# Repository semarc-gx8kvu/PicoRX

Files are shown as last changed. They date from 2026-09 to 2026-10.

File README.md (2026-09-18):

SEMARC Version of the PicoRX
============================

As a group we have taken Jon Dawson's design and created:

+ Our own PCB
+ The Box
+ Modifications to the Code

How we modify this fork is up to us as a group. I'm going to suggest that we have a *SEMARC* folder that contains our PCB and Box designs. But we *shouldn't* put code changes in there. I suggest that we put code changes in branches, and then decide as a group whether to include these in the main branch, or maybe even consider submitting pull requests to Jon's original repository.

Pi Pico Rx - A crystal radio for the digital age?
=================================

My first step into the world of electronics was with a crystal radio, just like this one. 

crystal radio

Back then, I don't think it has ever occurred to me that I could make a radio myself, so I wasn't expecting it to work. But when I put the earphone in, I was amazed to hear very faint sounds coming through. I couldn't believe that building a radio could be so simple, and the best part was, it didn't need any batteries! That little experience sparked my interest in electronics.

Times have certainly changed since then, and today, we find ourselves in a golden age for electronics enthusiasts. Back in the ninteen eightees, I could have never imagined that my pocket money would one day buy a device with computing power that could have filled an entire room just a few decades ago.

I often wonder how we can still capture that sense of awe and excitement from my first crystal radio experience. Is it still possible to create something simple yet captivating? 

The Pi Pico Rx - may be the answer to that question. While it may not be quite as straightforward as the crystal radio, the Pi Pico Rx presents a remarkably simple solution. Armed with just a [Raspberry Pi Pico](https://www.raspberrypi.com/products/raspberry-pi-pico/), an analogue switch, and an op-amp, we now have the power to construct a capable SDR receiver covering the LW, MW, and SW bands. With the ability to receive signals from halfway around the globe. I can't help but think that my younger self would have been truly impressed!

concept

Features
--------

+ 0 - 30MHz coverage
+ 250kHz bandwidth SDR reciever
+ CW/SSB/AM/FM reception
+ OLED display
+ simple spectrum scope
+ Headphones/Speaker
+ 500 general purpose memories
+ runs on 3 AAA batteries
+ less than 50mA current consumption

Development
-----------

concept

Pi Pico Rx is currently at the experimental prototyping stage, but it does work. [Read the Docs](https://101-things.readthedocs.io/en/latest/radio_receiver.html) for more technical details!

Getting the Code
----------------

You can find a precompiled binary for PiPicoRx [here](https://github.com/dawsonjon/PicoRX/releases). If you want to build from the C++ source files, follow these instructions.

```
  sudo apt install git
  git clone https://github.com/dawsonjon/PicoRX.git
  cd PicoRX
  git submodule init
  git submodule update
```

User Manual
-----------

You can find the user manual for the PiPicoRx [here](https://github.com/dawsonjon/PicoRX/raw/master/user_manual/Pi%20Pico%20Rx%20User%20Manual.pdf).

Install Pi Pico SDK
-------------------

Follow the [Getting started with the Raspberry Pi Pico](https://datasheets.raspberrypi.com/pico/getting-started-with-pico.pdf) quick start guide to install the C/C++ SDK.

```
  sudo apt install wget #if wget not installed
  wget https://raw.githubusercontent.com/raspberrypi/pico-setup/master/pico_setup.sh
  chmod +x pico_setup.sh
  ./pico_setup.sh
```

For windows users, this page provides and [installer](https://www.raspberrypi.com/news/raspberry-pi-pico-windows-installer/) that makes the process much simpler.

Build Projects
--------------

```
  mkdir build
  cd build
  cmake -DPICO_BOARD=pico -DPICO_SDK_PATH=~/pico/pico-sdk ..
  make
```

```
  mkdir build
  cd build
  cmake -DPICO_SDK_PATH=~/pico/pico-sdk -DPICO_BOARD=pico2 -DPICO_PLATFORM=rp2350-arm-s ..
  make
```

```
  mkdir build
  cd build
  cmake -DPICO_SDK_PATH=~/pico/pico-sdk -DPICO_BOARD=pico2 -DPICO_PLATFORM=rp2350-riscv ..
  make
```

Credits
-------

Massive thanks to everybody who has contributed and given feedback on this project. Thanks to
all your efforts, we’re closer than ever to making radio more accessible,
innovative, and community-driven.

The project uses the Universal 8-bit Graphics Library (u8g2) library by
olikraus@gmail.com, the pico_ssd1306 display library by David Schramm and the
ILI934X display driver by Darren Horrocks.

Special Thanks to:

Mariusz Ryndzionek for contributing IQ Imbalance Correction, De-emphasis
filter, USB audio, U8G2 integration, Synronous AM Demodulation and many other
enhancements.

Penfold42 for Gain Calibration, Frequency Scanning, Spectrum Zoom, Multiple home screen
views, Animated Splash Screen, Support for multiple displays/configurations and
many other enhancements.

Robert Nickels (W9RAN) and Jim Reagan (W0CHL) for their support and
encouragements and for the enormous effort they have both put in testing,
debugging, feedback and suggestions.

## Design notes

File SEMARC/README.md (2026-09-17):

SEMARC Specific Folder
======================

This folder should contain things that are only relevant to our group. That will include the case and the PCB.

I suggest that have sub-folders, maybe **case** or **box** and **PCB**. But I'll leave that to whoever adds the files. For now, the files should added straight onto the master branch.

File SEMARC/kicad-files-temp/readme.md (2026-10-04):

# How I added these files

From my laptop, I opened a powershell terminal and typed in the following commands:

```powershell
git clone git@github.com:semarc-gx8kvu/PicoRX.git
cd .\PicoRX\
git branch m0twm-add-kicad-files
git checkout m0twm-add-kicad-files
```

I then added the files in file explorer

Back in powershell, I executed the following commands:

```powershell
git add *
git commit -m 'Add schematics and pcb layouts'
git push --set-upstream origin m0twm-add-kicad-files
```

On the github website, the new branch automatically shows up and prompts you to submit a **pull request**:

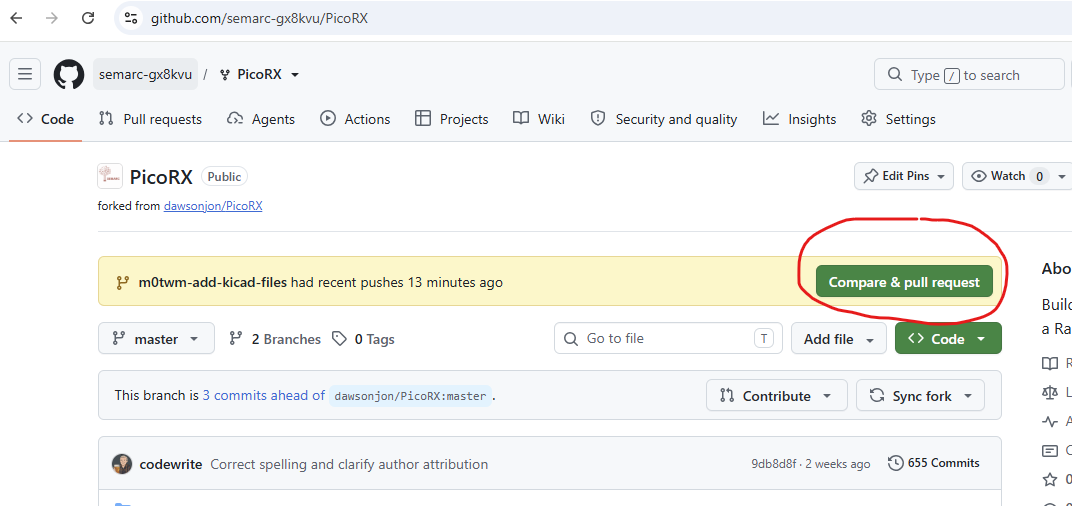
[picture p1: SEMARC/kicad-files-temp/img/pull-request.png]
Pull Request


On the next page, you get to name the pull request and set a description. Because this is a forked repository, you have to set the repository to the SEMARC one, because by default it will send a pull request to the base repository (jondawson) and you probbaly don't want that!

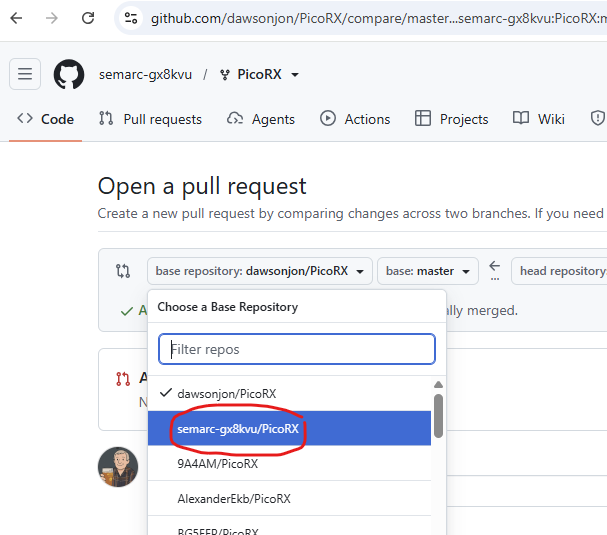
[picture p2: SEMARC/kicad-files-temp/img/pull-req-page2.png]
Pull Request Page 2


Admins get notified, and should approve the pull request as soon as possible. This is the standard approach and ensures that there are no conflicts. The files are now available on the main branch (which in this case is called master).

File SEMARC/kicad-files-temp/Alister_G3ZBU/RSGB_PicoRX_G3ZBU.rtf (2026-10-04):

RSGB Construction Competition 2026
Entry by Al Watt, G3ZBU

The PicoRX.

A few years ago I submitted an entry which used a Raspberry Pi Pico’s PIO subsystem as a 0-30MHz quadrature signal generator. That idea has been taken to a considerably higher level by Jon Dawson and his design published online in GitHub and 101 Things. I am sure that he did not copy my signal generator design because it seems to be an obvious thing to do with it.

The SEMARC club has chosen this project for 2026 and will design PCBs and housings.

His PicoRX is a fully-featured minimal-cost long-wave to 30MHz receiver and decodes AM, FM, LSB, USB and CW. All it requires is a £5 Pico, cheap OLED display, 3 push-buttons, shaft encoder, cheap dual op-amp and a multiplexer IC, plus a few resistors and capacitors. The receiver can be improved by the addition of band-pass filters and an Si5351 module if one really wants to splash out. His design uses surface-mount low-pass filters but my build will use larger components with legs, for experimentation.

The Pico has two 12-bit ADCs and they collect I and Q samples from a low IF of DC to 12kHz. Oversampling is enabled and that gives an improvement on the dynamic range. A pre-amp would be useful for the higher bands but on 40m the performance is perfectly acceptable thought broadcast interference could be an issue at night. There is excellent AGC, all done in software.

Another brilliant feature is the USB interface which provides audio output and CAT commands. This is similar to rigs costing £1,000. FLDIGI can be used to decode RTTY, PSK and MFSK signals. I have also used it with EI5DI’s SD logger. It also runs under DXLab Commander, so a PC can be used to select mode and frequency. CAT control is sent to COM3 on this Windows PC.

Because the minimum build would cost about £10 + PCB, it is ideal for schools. There are 512 memories covering not only Amateur bands but also LW, MW and SW broadcast stations, plus all the 27MHz CB channels. These may be easily changed and downloaded into the Pico.

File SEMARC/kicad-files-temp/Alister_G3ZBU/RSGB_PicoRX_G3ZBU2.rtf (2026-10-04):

RSGB Construction Competition 2026
Entry by Al Watt, G3ZBU, 27th Feb 2026.

The PicoRX.

A few years ago I submitted an entry which used a Raspberry Pi Pico’s PIO subsystem as a 0-30MHz quadrature signal generator. That idea has been taken to a considerably higher level by Jon Dawson and his design as published online in GitHub and 101 Things. I am sure that he did not copy my signal generator design because it seems to be an obvious thing to do with it.

The SEMARC club has chosen this project for 2026 and will design PCBs and housings.

His PicoRX is a fully-featured minimal-cost long-wave to 30MHz receiver and decodes AM, FM, LSB, USB and CW. All it requires is a £5 Pico, cheap OLED display, 3 push-buttons, shaft encoder, cheap dual op-amp and a multiplexer IC, plus a few resistors and capacitors. The receiver can be improved by the addition of band-pass filters, a small TFT screen and an Si5351 module if one really wants to splash out. His design uses surface-mount low-pass filters but my build will use larger components with legs, for experimentation.

The Pico has two 12-bit ADCs and they collect I and Q samples from a low IF of DC to 12kHz, from a Tayloe mixer. Oversampling is enabled and that gives an improvement on the dynamic range. A pre-amp would be useful for the higher bands but on 40m the performance is perfectly acceptable though Jon states that broadcast interference could be an issue at night. I have yet to try filters but they would be useful in attenuating any reception at multiples of the operating frequency.

There is excellent AGC, it’s all done in software as opposed to PIN diodes etc.

Another brilliant feature is the USB interface (USB as in Universal Serial Bus) which provides both audio output and CAT commands. This is similar to rigs costing upwards of £1,000. FLDIGI can be used to decode RTTY, PSK and MFSK signals. I have also used the USB CAT with EI5DI’s SD logger so that typing a frequency into the call-sign box causes the PicoRX to jump to that frequency. CAT also runs under DXLab Commander, so a PC can be used to select mode and frequency. CAT control is sent via COM3 on this Windows PC. However I have not yet managed to get FLRIG to play.

Another problem is that there are audible clicks when the tuning knob is rotated and Jon suggests that it is because the CPU clock is being reset to another frequency. That is done because the PIO subsystem cannot generate enough frequency resolution on the higher bands.

There are many Amateurs who are not keen on rigs with loads of menus and far prefer buttons, switches and knobs to perform the desired function. I have modified the software such that it uses two unallocated UART pins on the Pico to enable CAT by serial data. For a proof-of-concept I have connected this new serial data pair to a PIC which reads three push-buttons and controls green and red LEDs in each of the three switches. I have labelled these switches USB, CW and LSB. When a switch is pressed, its green LED is switched on and the relevant CAT command sent to the Pico at 19,200Bd. Poll commands are sent every second and the return packet is used to clear the green LED and switch on the correct red LED. In principal, I can extend the push-button scheme by adding more PICs, and I could also add potentiometers easily and build a menu-free receiver.

Because the minimum build would cost about £10 + PCB, it is ideal for schools. There are 512 memories covering not only most Amateur bands but also LW, MW and SW broadcast stations, plus all the 27MHz CB channels. These may be easily changed and downloaded into the Pico using a CSV formatted file.

I intend to generate an Amateur-only CSV file which includes all our band allocations. These can include the most popular FreeDV channels as that is a very exciting ‘new’ mode (I think it’s over 10 years old actually!); FreeDV can be decoded by a free program running on a PC or laptop and connected with the USB CAT/audio cable.

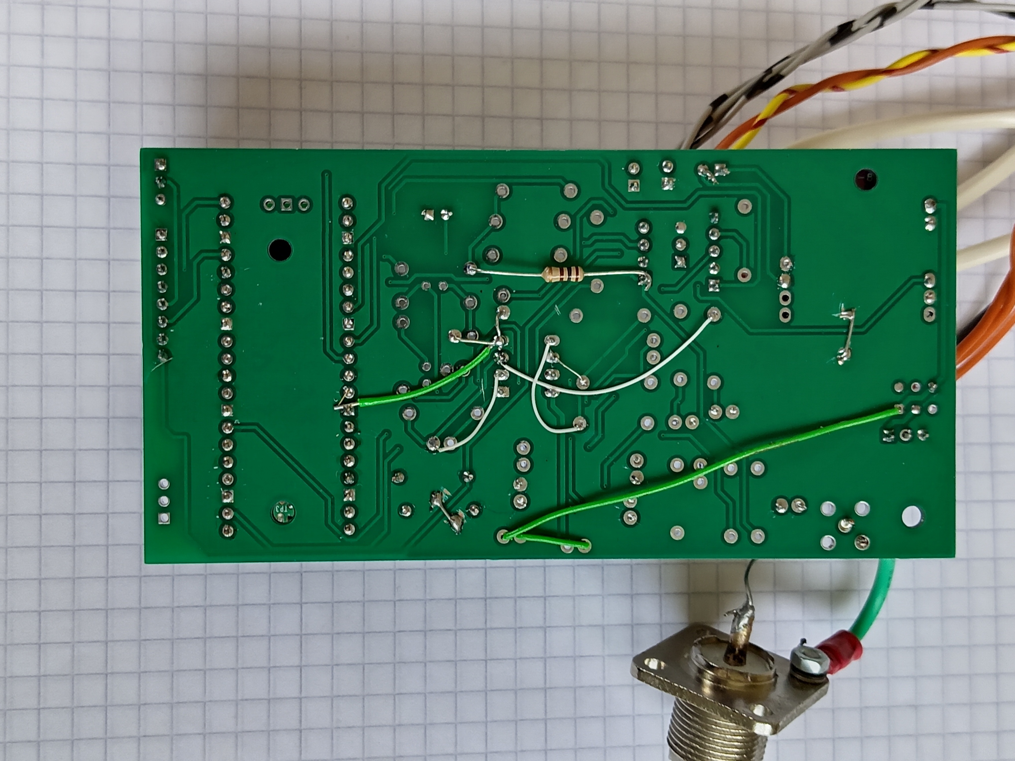
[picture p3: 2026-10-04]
SEMARC/kicad-files-temp/Alister_G3ZBU/IMG_20260323_111353_bot.jpg

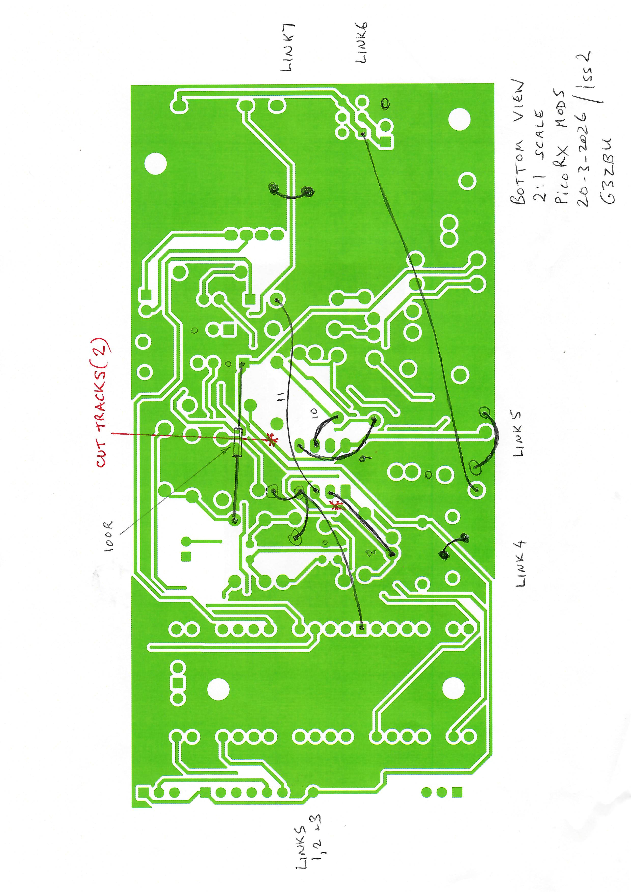
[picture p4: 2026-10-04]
SEMARC/kicad-files-temp/Alister_G3ZBU/scanPicoRX_bot_iss2.jpg

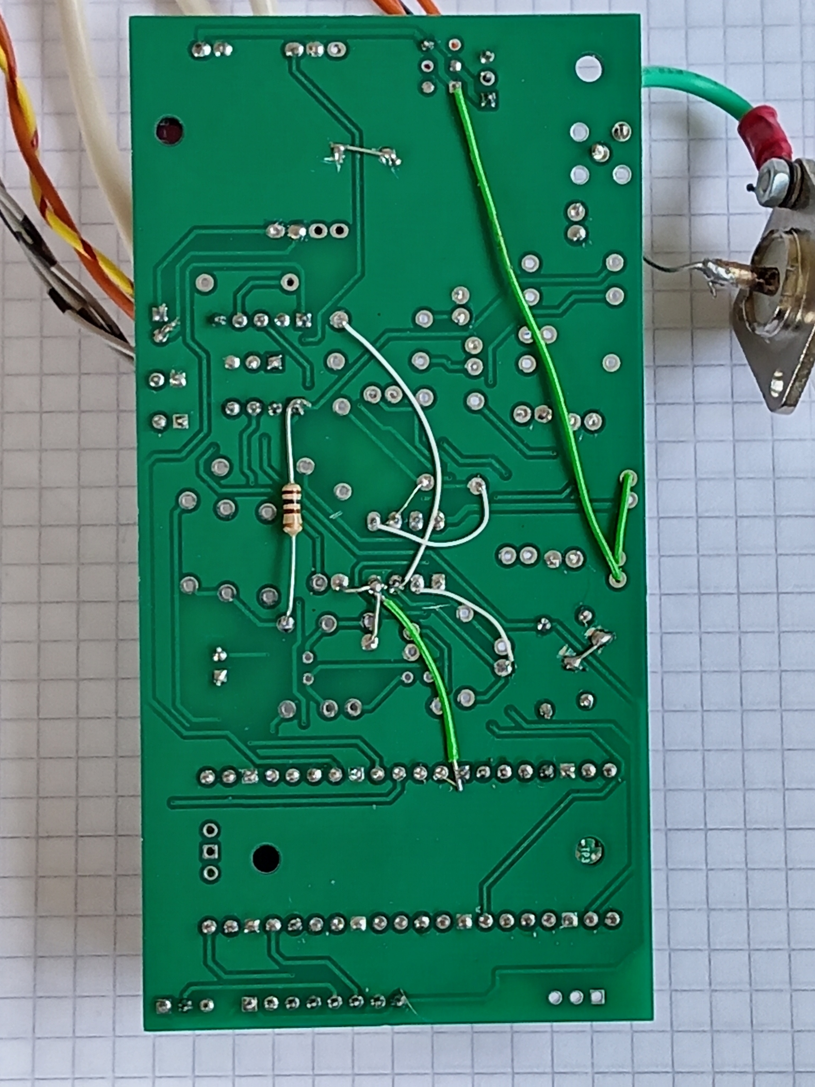
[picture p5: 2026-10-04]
SEMARC/kicad-files-temp/Alister_G3ZBU/IMG_20260323_111336_bot.jpg

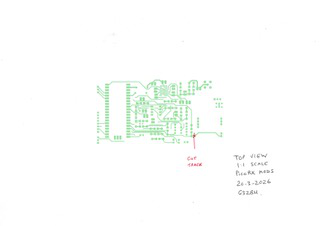
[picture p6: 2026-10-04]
SEMARC/kicad-files-temp/Alister_G3ZBU/scanPicoRX_TOP.jpeg

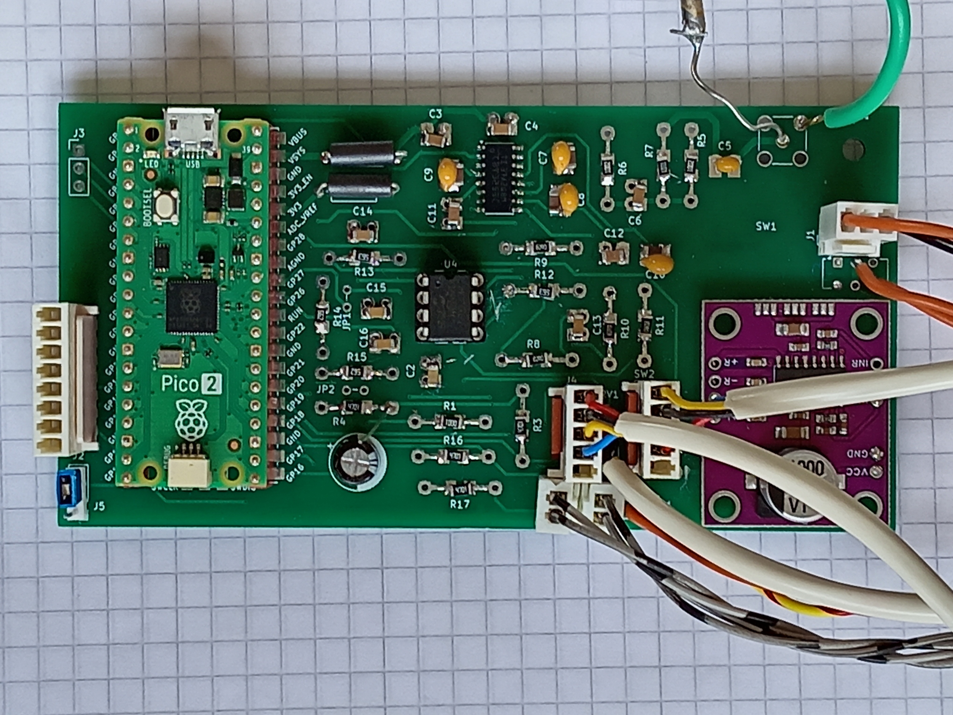
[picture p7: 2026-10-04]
SEMARC/kicad-files-temp/Alister_G3ZBU/IMG_20260323_111321_top.jpg

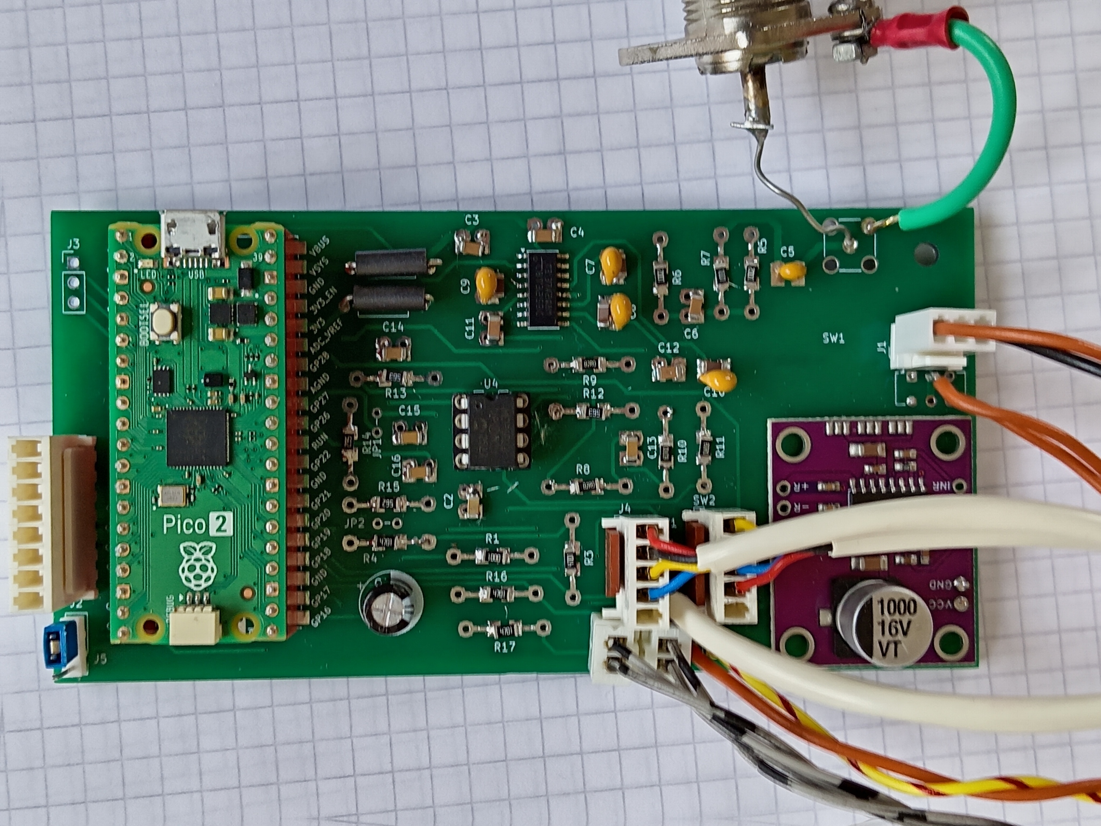
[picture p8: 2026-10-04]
SEMARC/kicad-files-temp/Alister_G3ZBU/IMG_20260323_111430_top.jpg

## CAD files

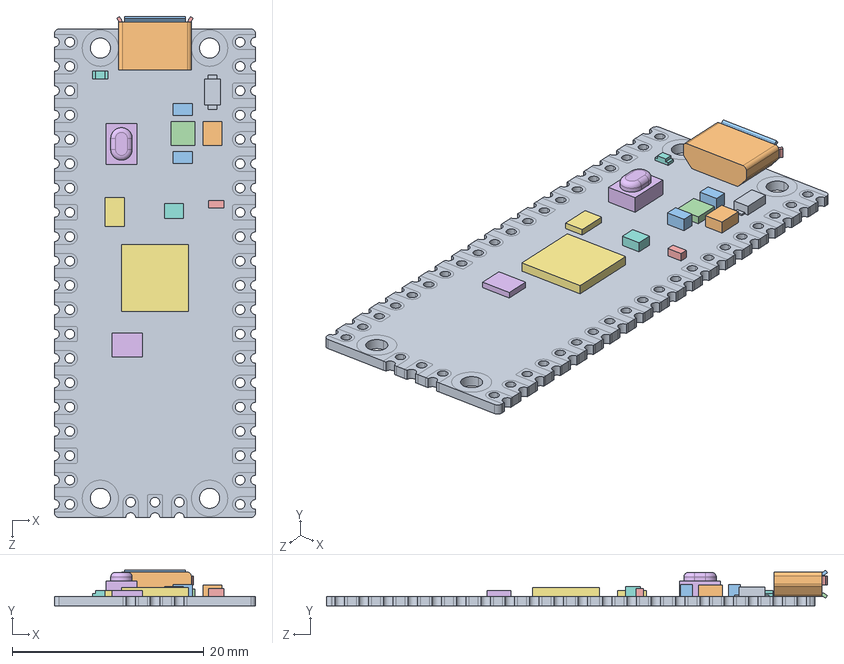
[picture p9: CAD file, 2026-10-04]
SEMARC/kicad-files-temp/Rob_G8ZAX/pico2.step
21.0 x 3.73 x 52.3 mm
PICO_REF_BOARD
PICO_REF_USB
PICO_REF_SWITCH
PICO_REF_MICROCONTROLLER
PICO_REF_LED
PICO_REF_COMP_1
PICO_REF_COMP_2
PICO_REF_COMP_3 x 2
PICO_REF_COMP_4
PICO_REF_COMP_5
PICO_REF_COMP_6
PICO_REF_COMP_7
PICO_REF_INDUCTOR

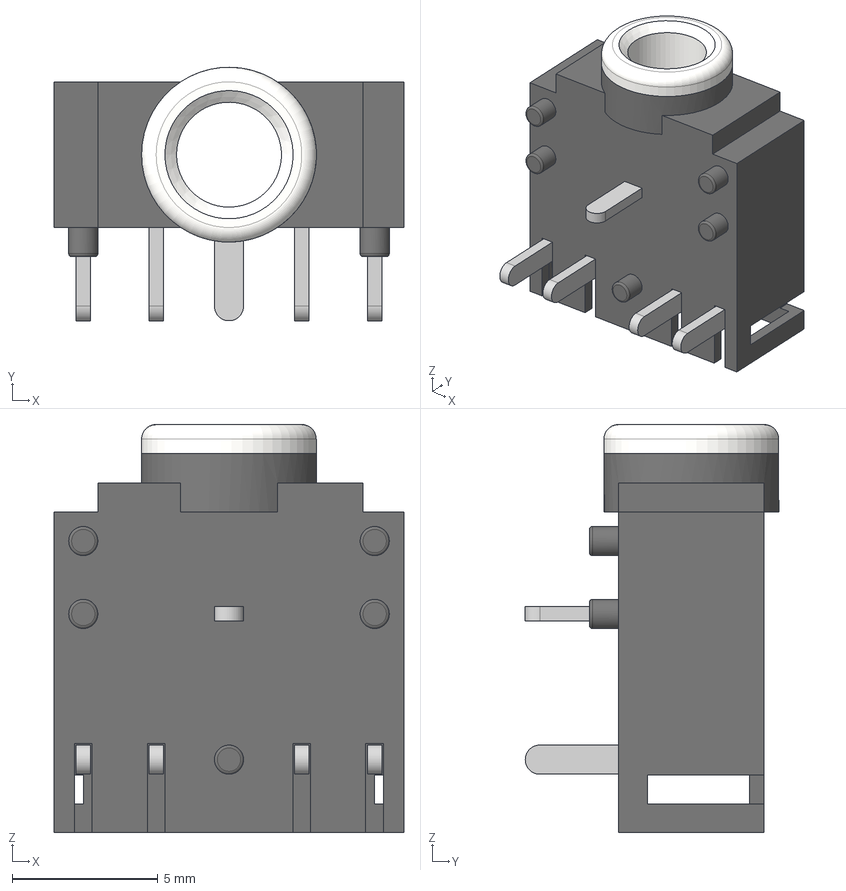
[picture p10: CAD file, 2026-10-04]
SEMARC/kicad-files-temp/Rob_G8ZAX/PicoRX_Footprints/pj-307.step
12.0 x 8.70 x 14.0 mm

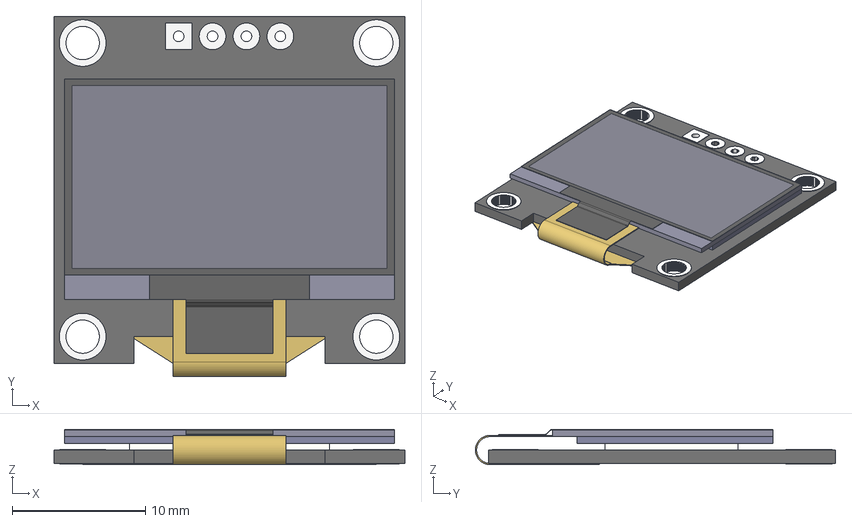
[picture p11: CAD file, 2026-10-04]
SEMARC/kicad-files-temp/Rob_G8ZAX/Display_OLED_0.96_128x64.step
26.3 x 27.0 x 2.65 mm
Body - PCB
Body - Back Panel
Body - Adhesive Pad
Body - Front Panel
Body - Flex Connector Bend
Body - Flex Connector Terminals
Body - Black Tape
Body - Protective Foil
Body - Screen Border
Extrude - Annular Rings

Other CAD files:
SEMARC/kicad-files-temp/Rob_G8ZAX/Pico-R3.step

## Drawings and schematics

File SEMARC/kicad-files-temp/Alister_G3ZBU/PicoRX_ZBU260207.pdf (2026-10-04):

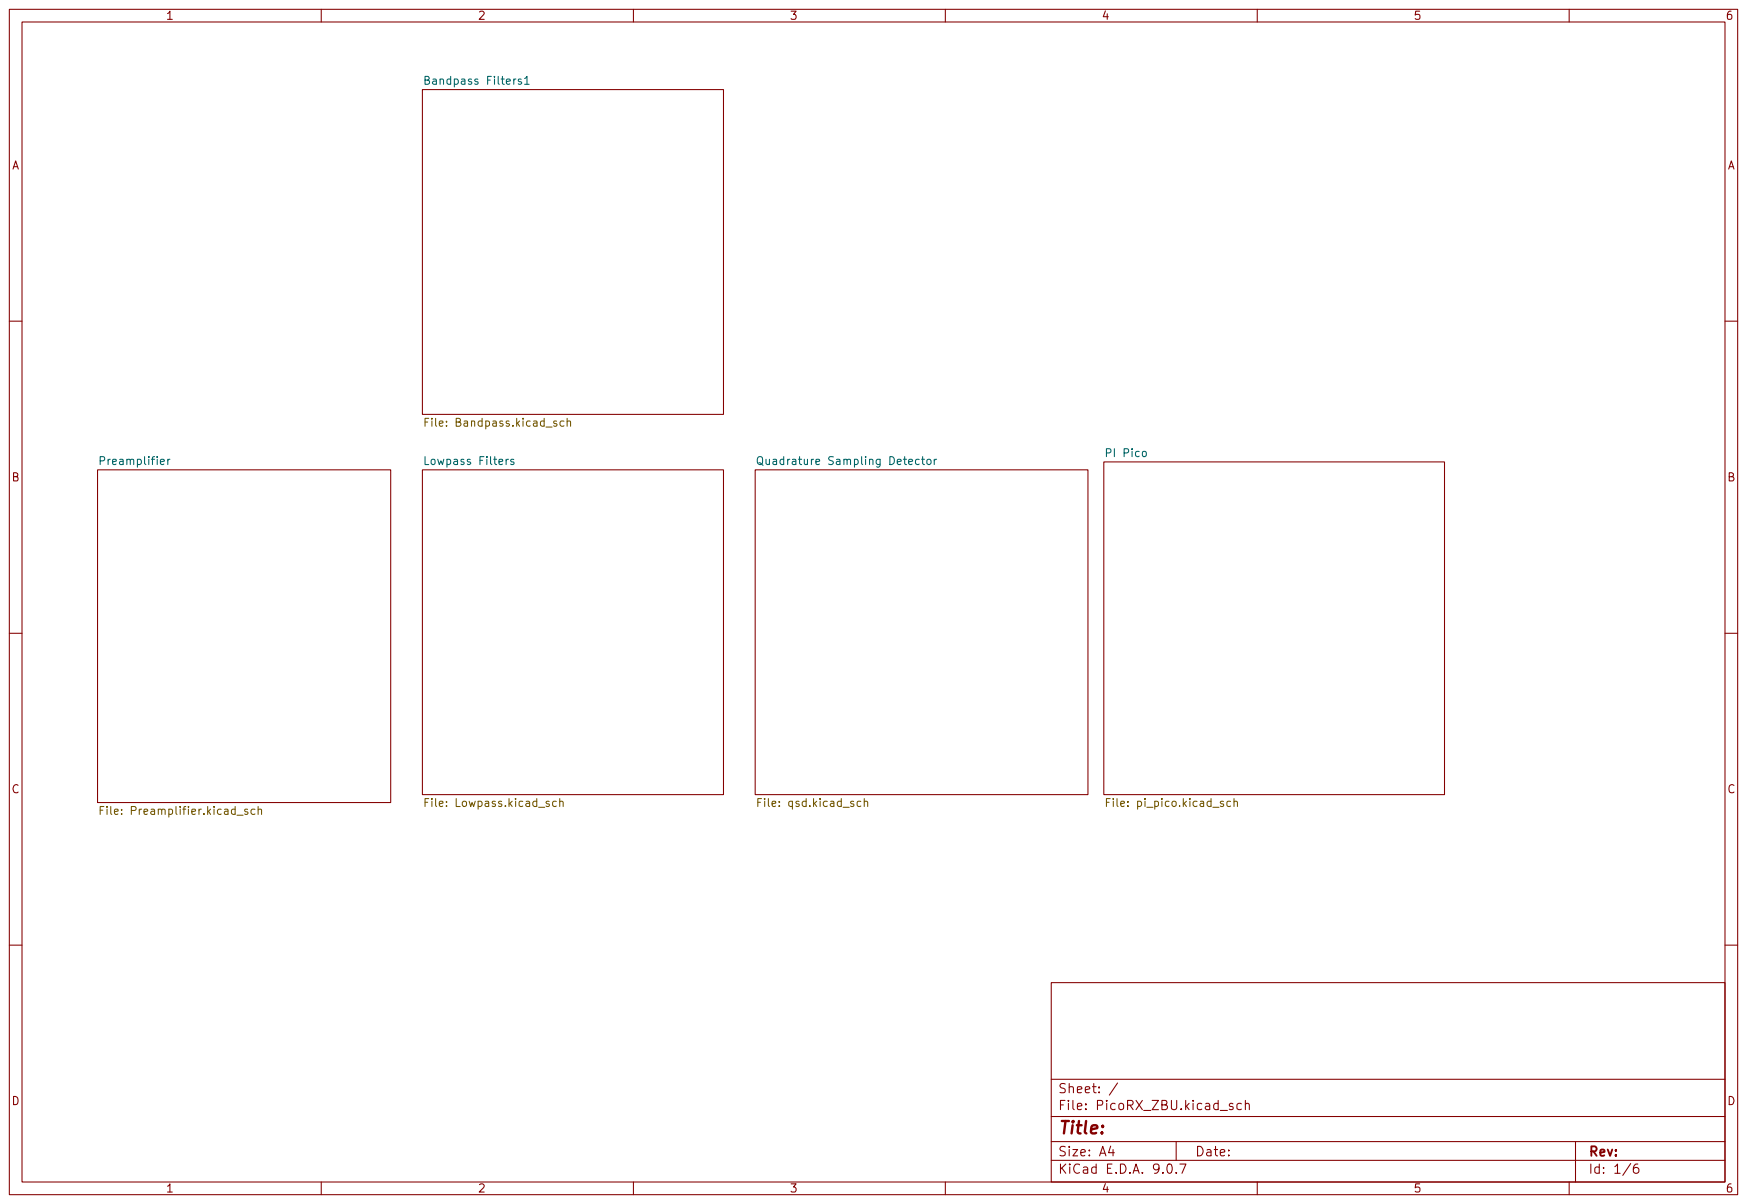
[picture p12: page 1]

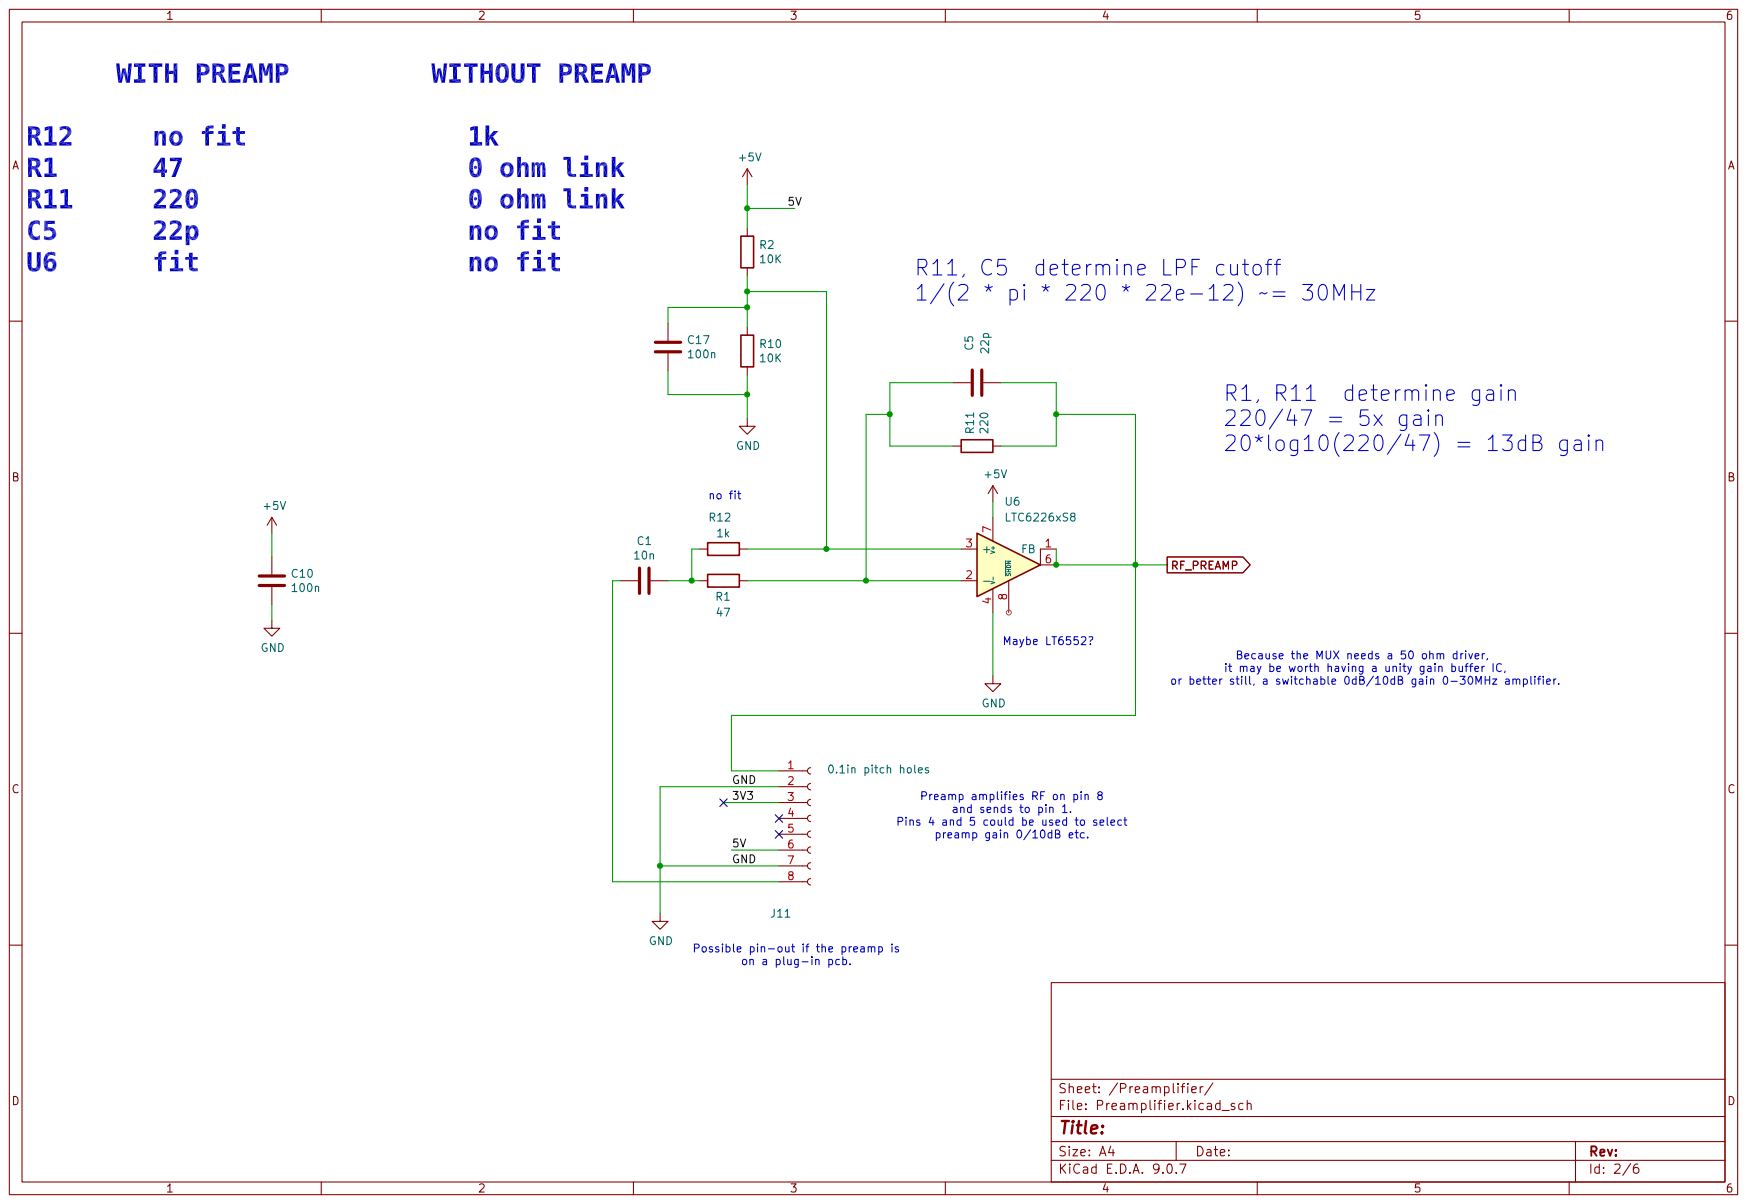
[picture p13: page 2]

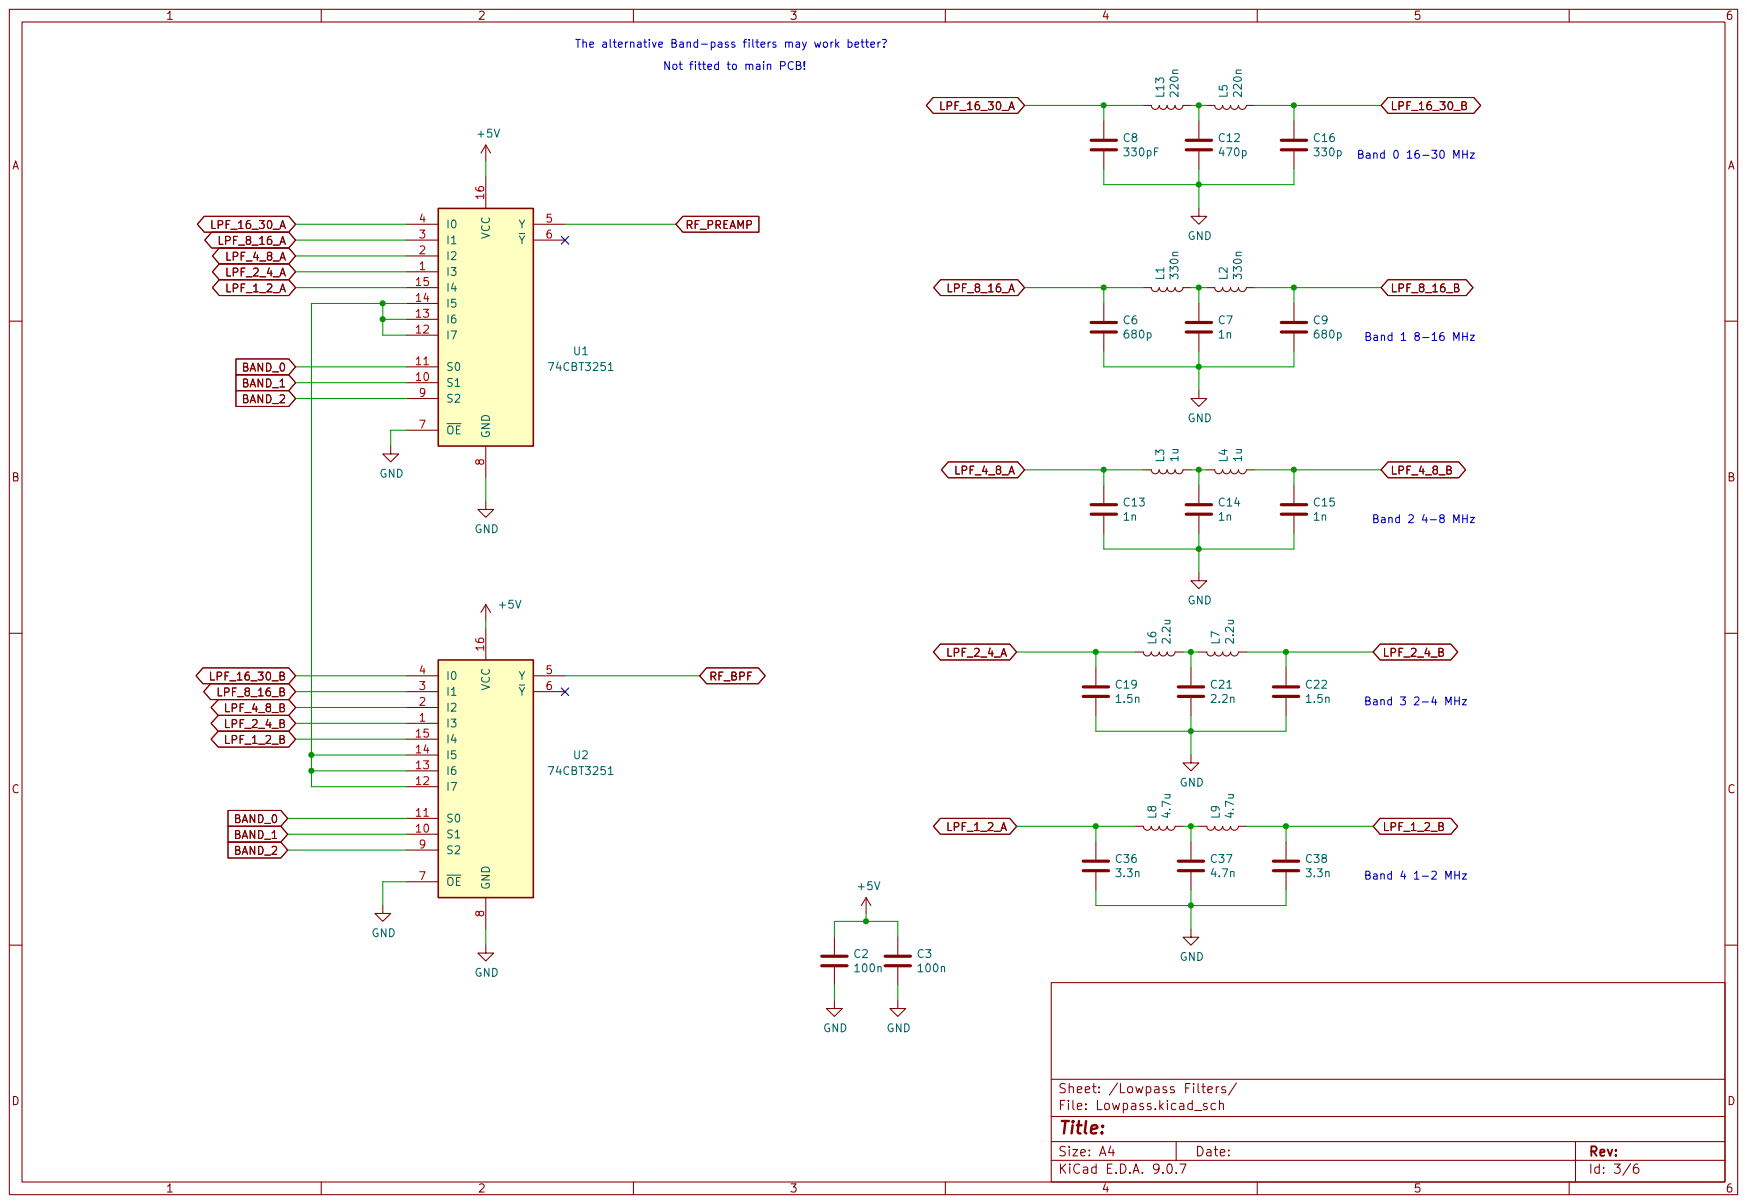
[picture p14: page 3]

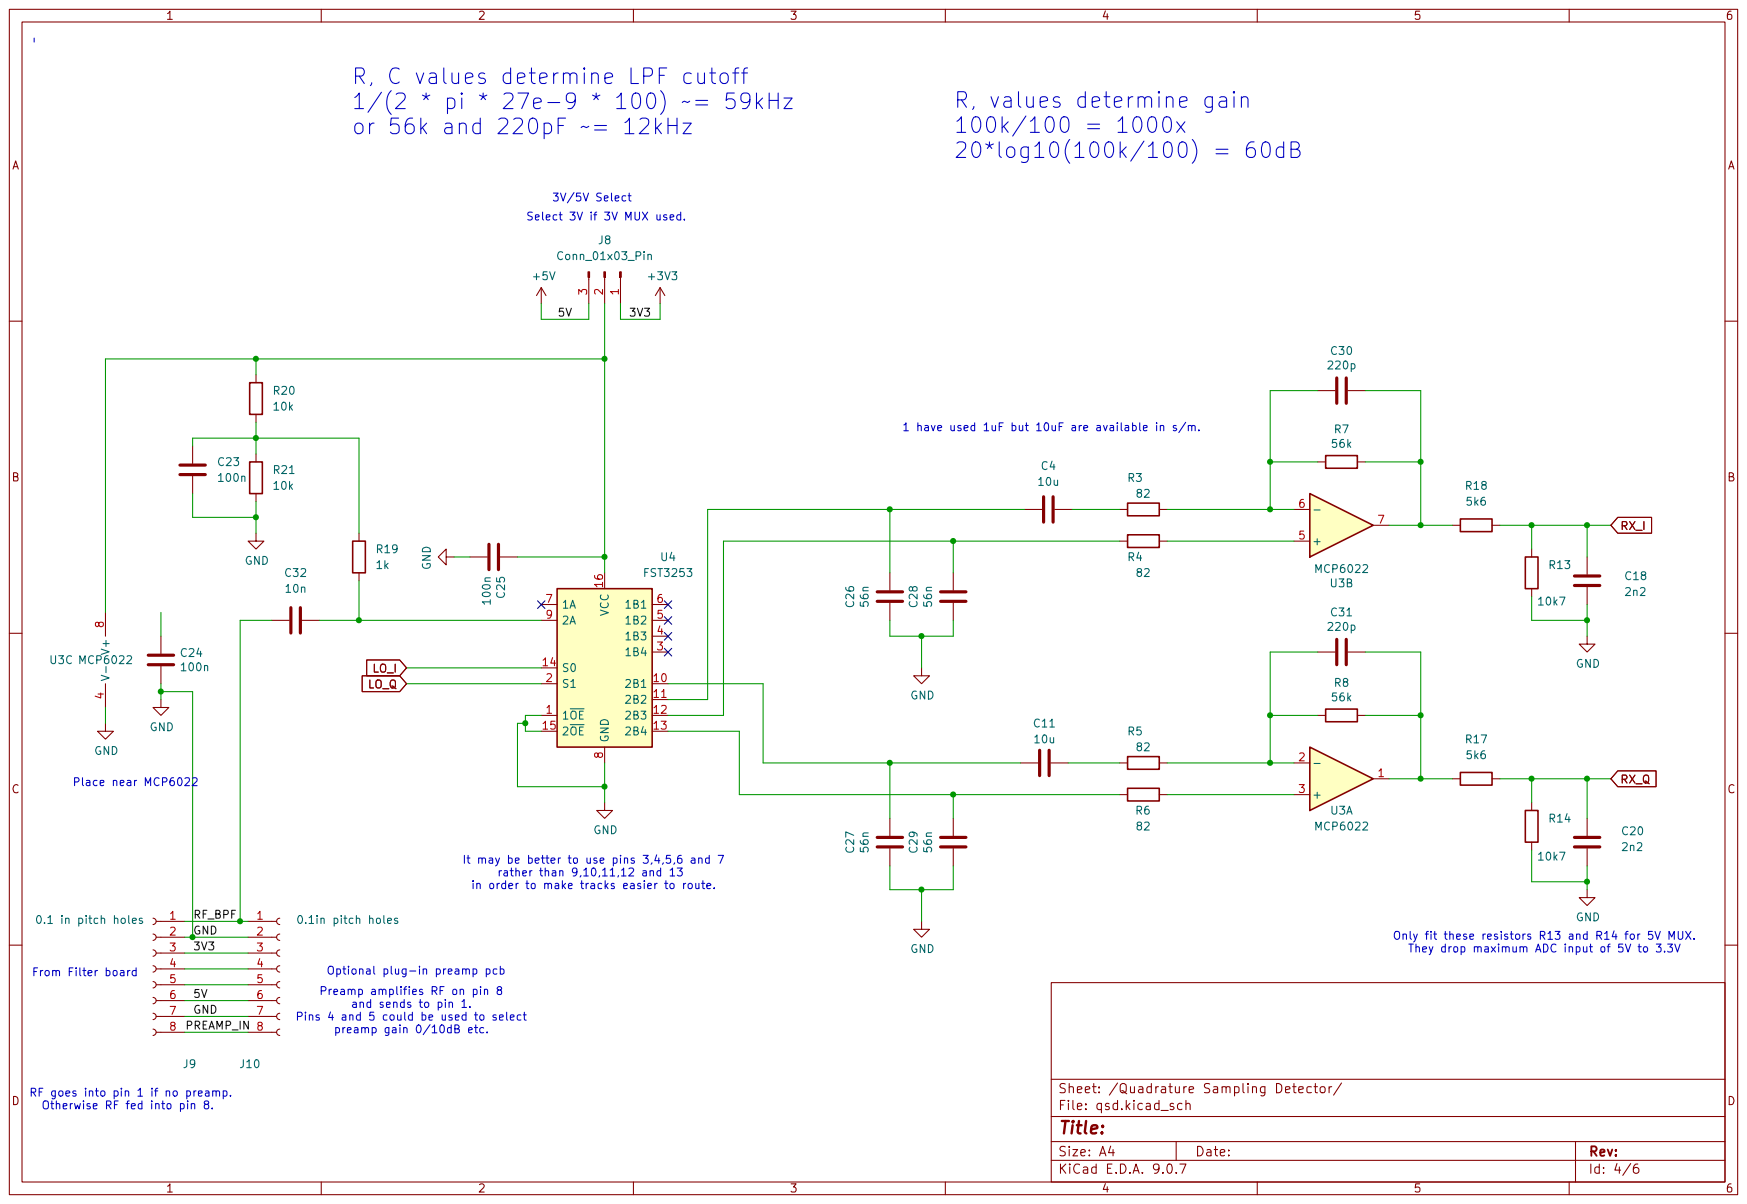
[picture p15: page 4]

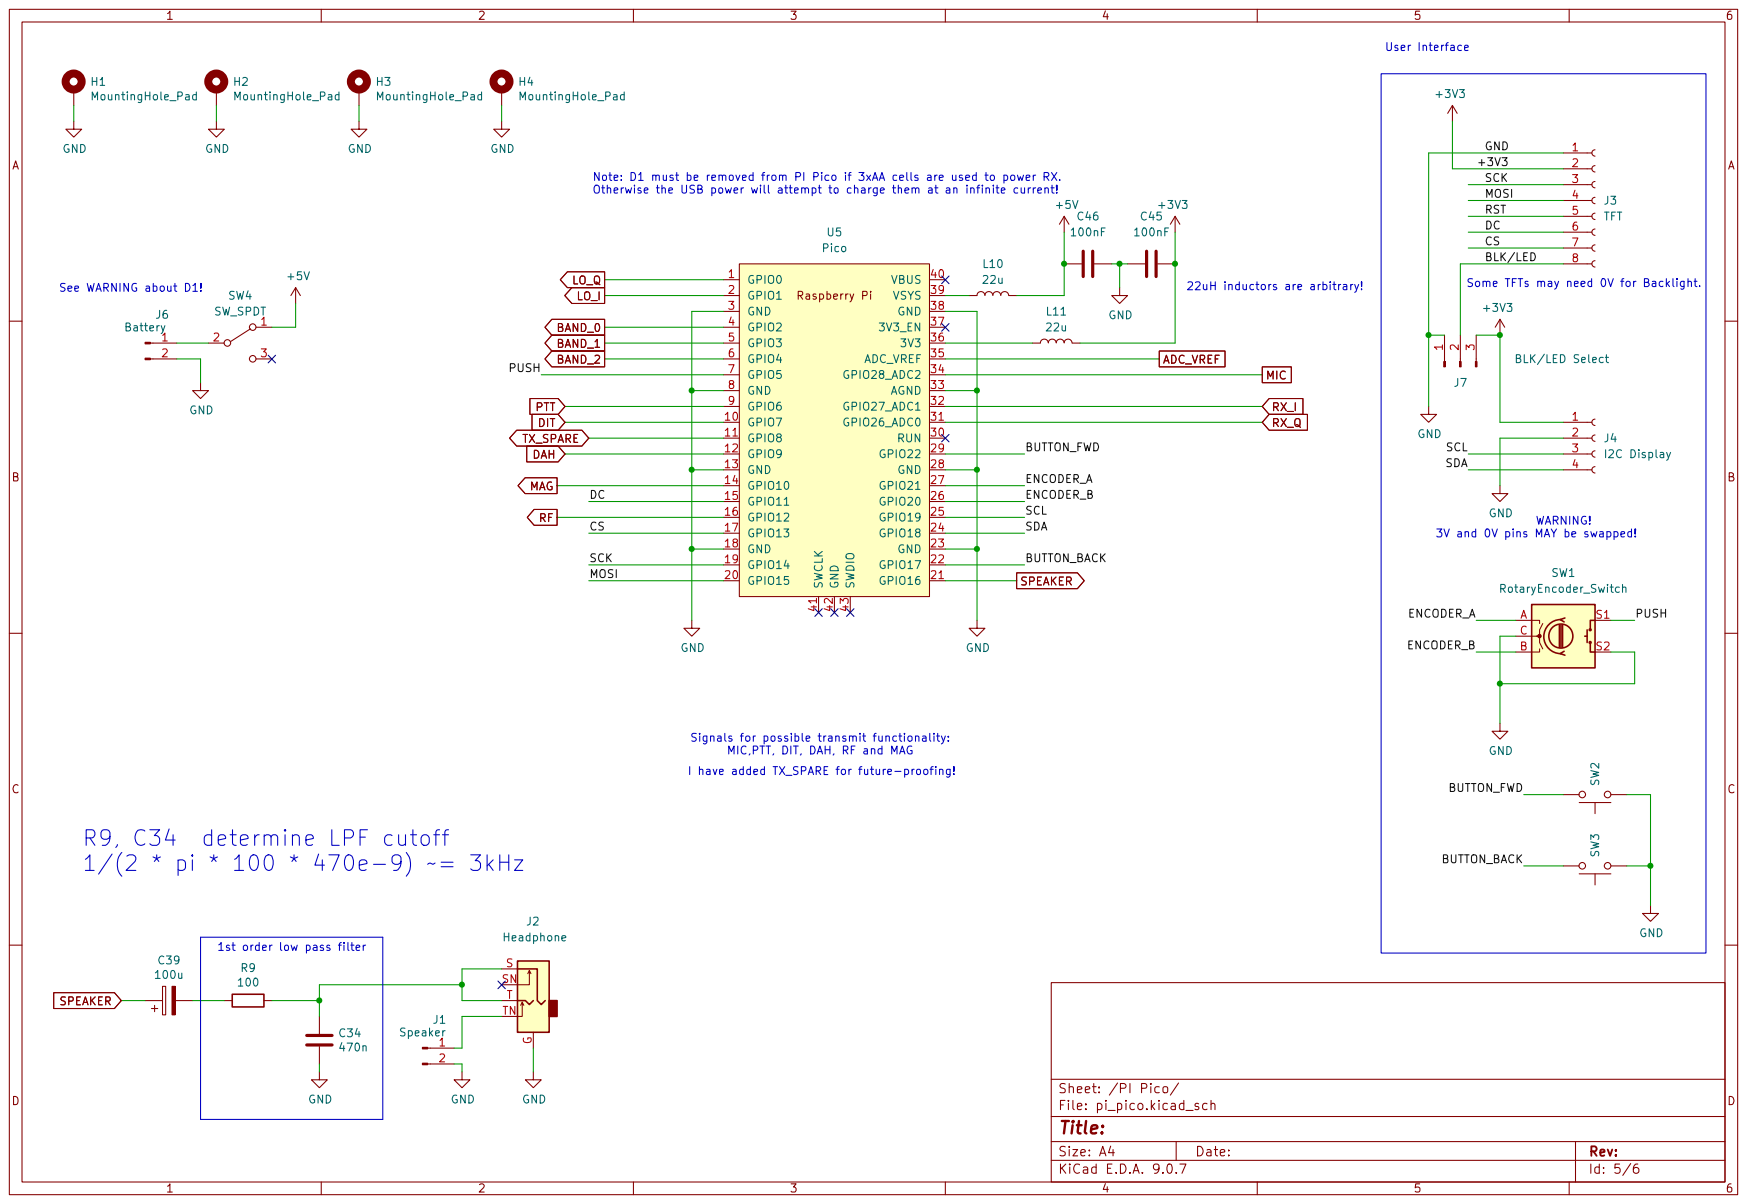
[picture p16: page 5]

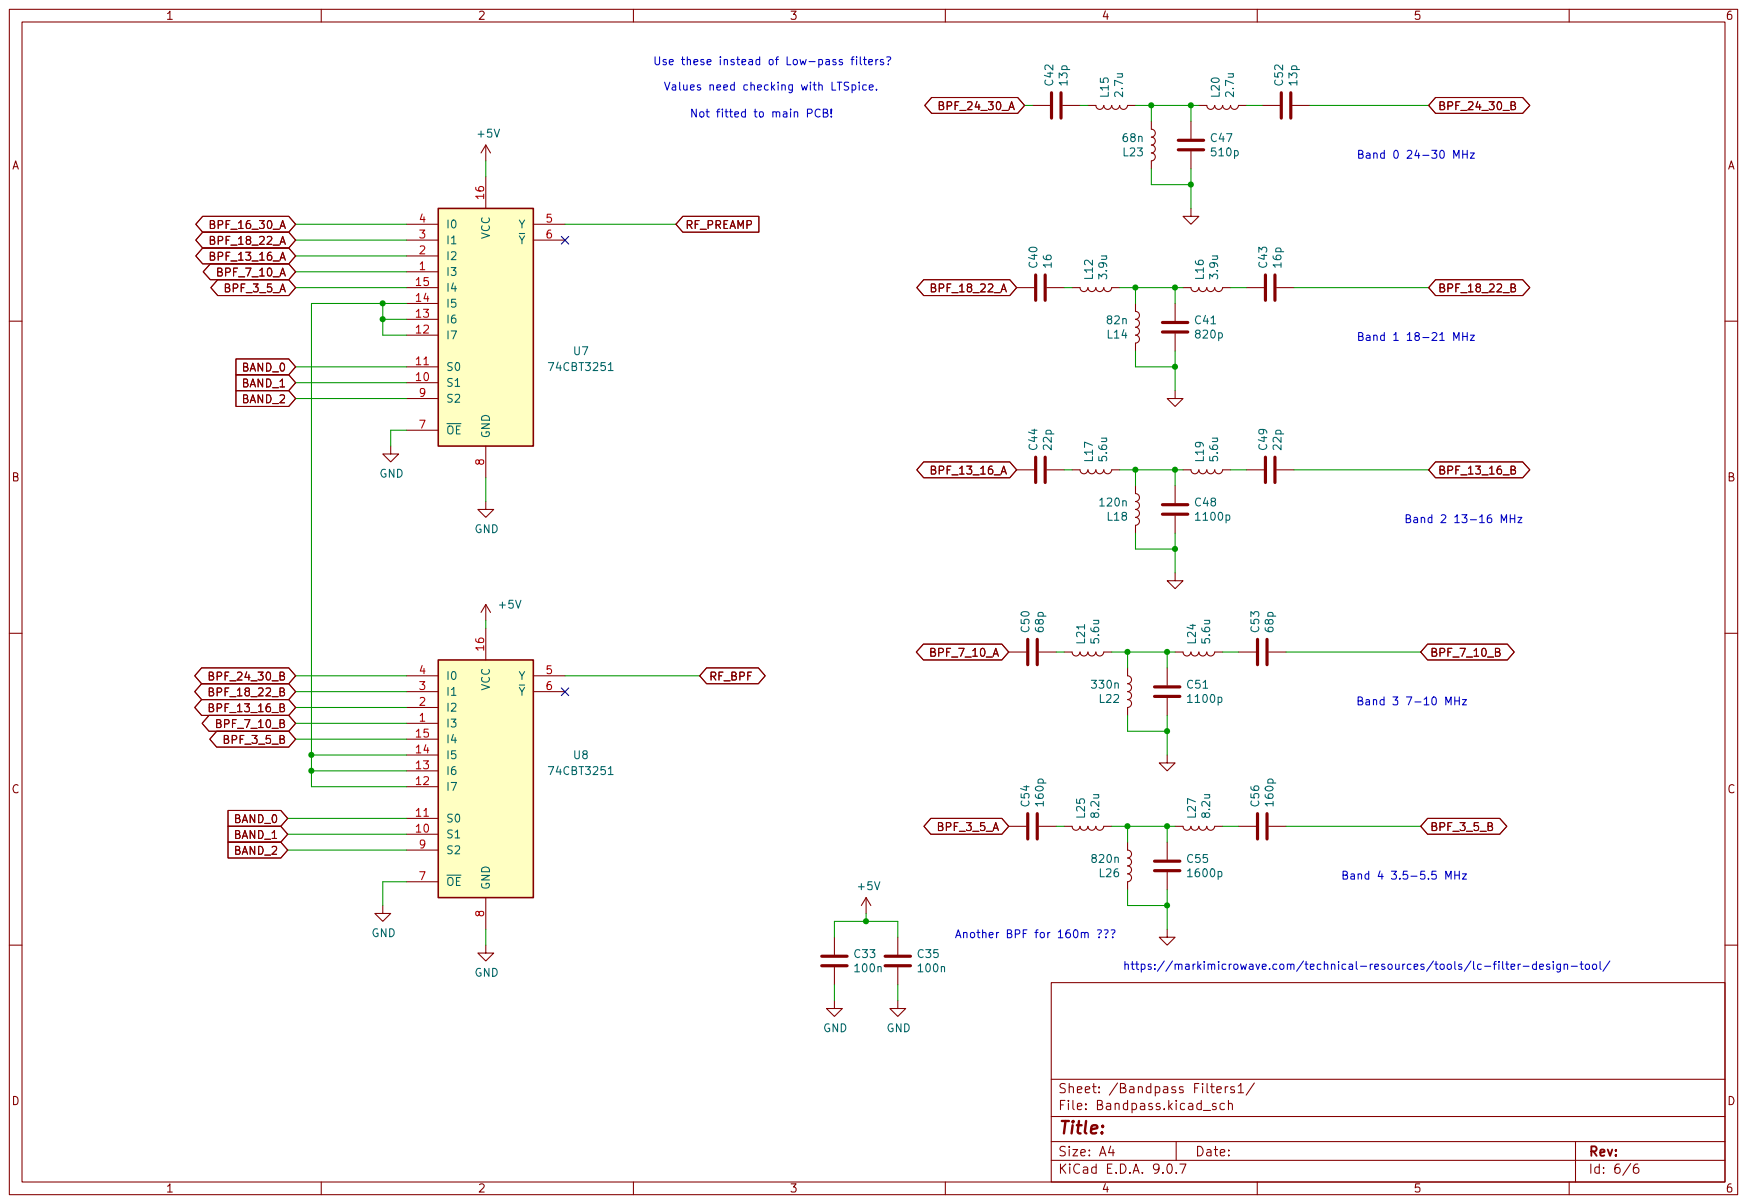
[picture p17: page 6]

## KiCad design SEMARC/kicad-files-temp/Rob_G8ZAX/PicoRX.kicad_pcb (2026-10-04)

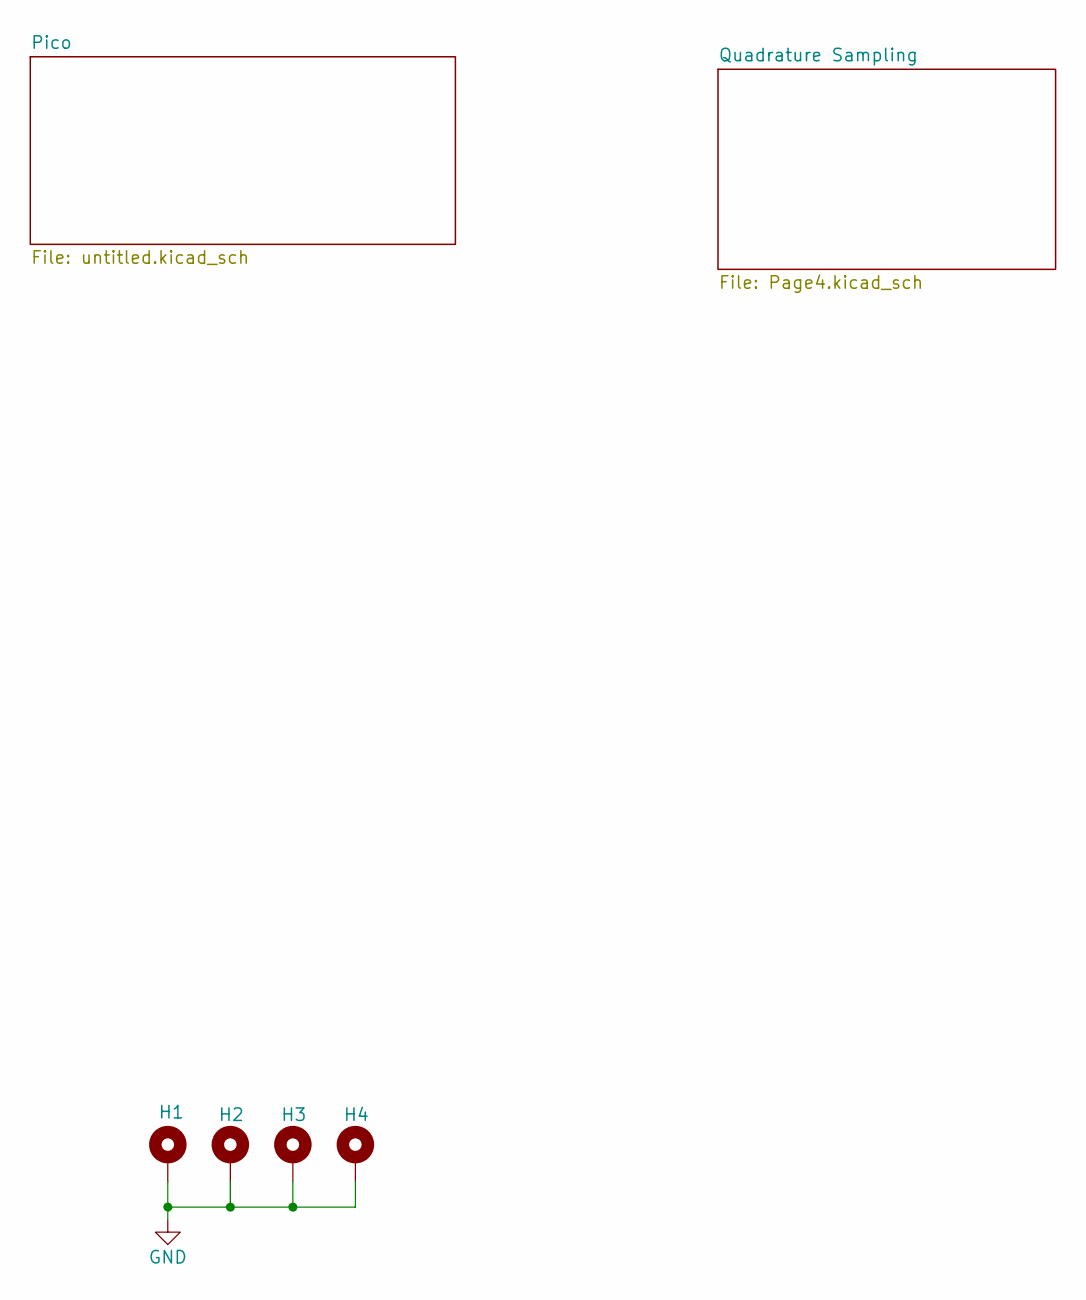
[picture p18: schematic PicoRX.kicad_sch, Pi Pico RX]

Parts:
H1, H2, H3, H4: MountingHole_Pad; MountingHole_3.2mm_M3_DIN965_Pad_TopBottom

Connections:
GND: H1.1, H2.1, H3.1, H4.1; also elsewhere on the board

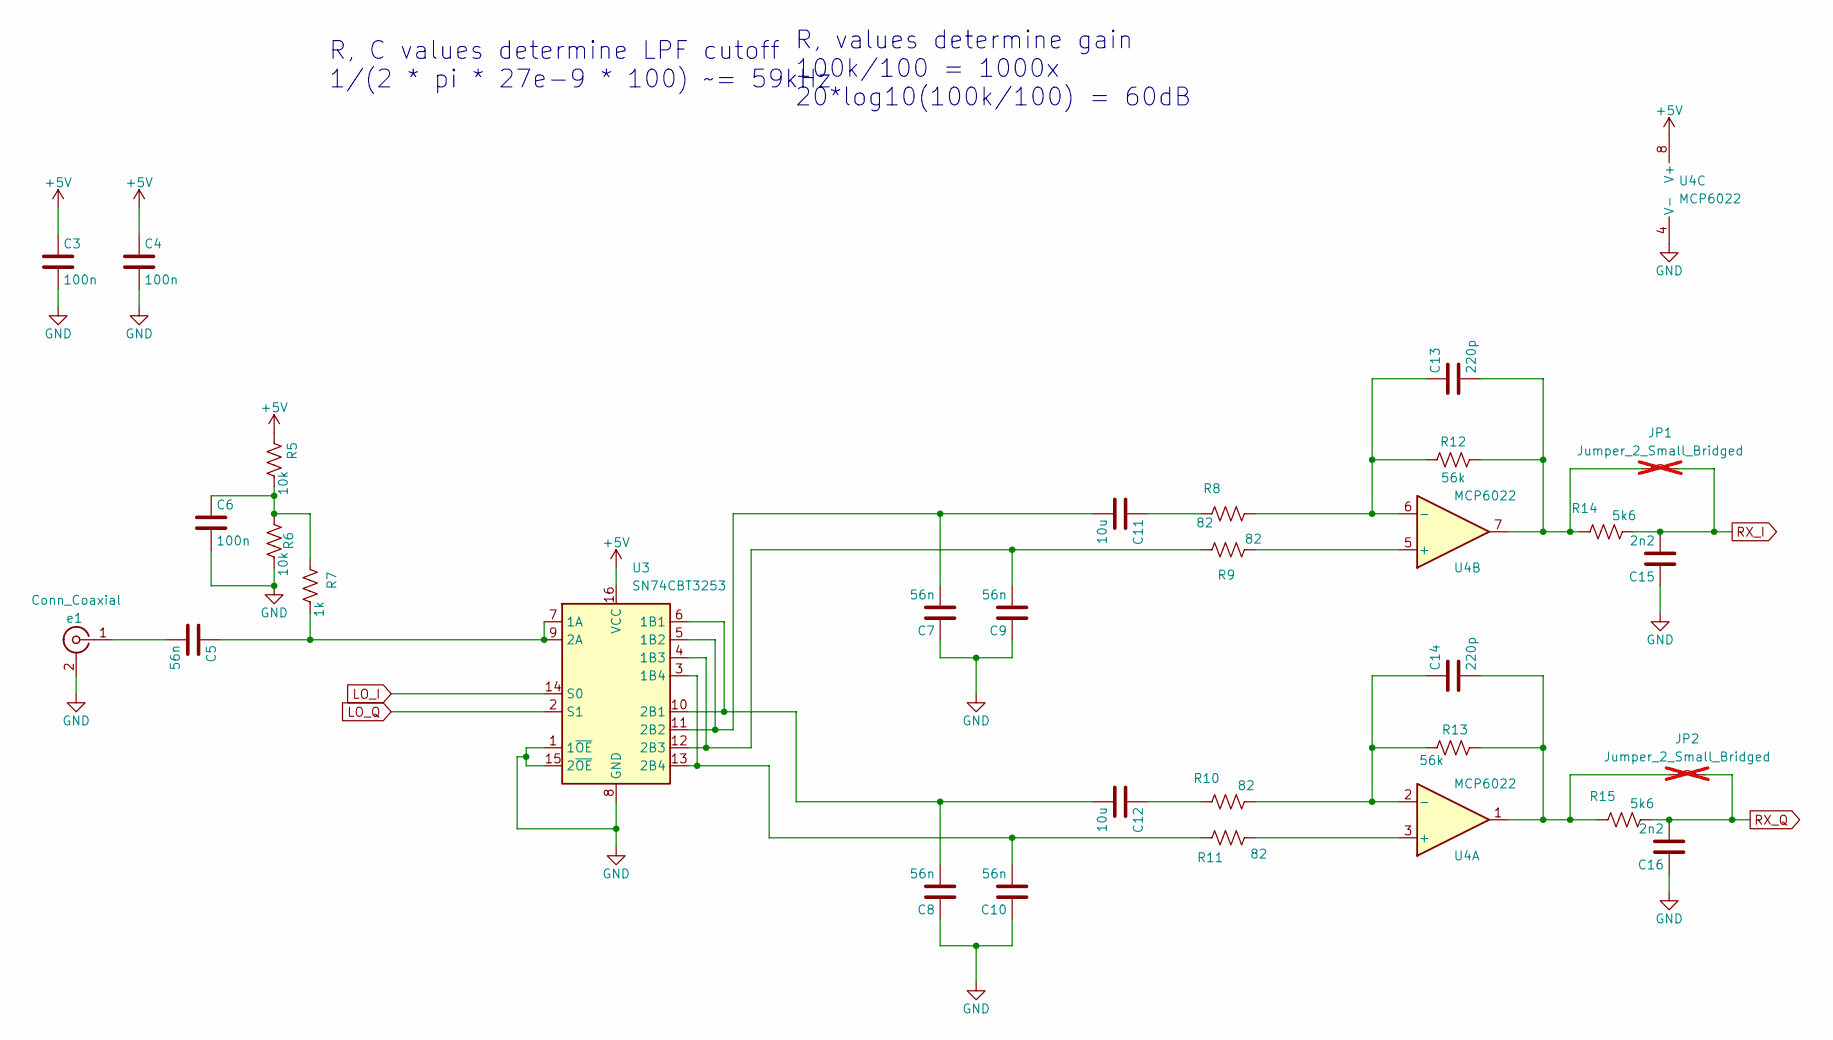
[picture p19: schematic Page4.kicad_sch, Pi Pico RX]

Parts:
C3, C4, C6: 100n; C_UNIV_THT2p54_SMD1206
C5, C7, C8, C9, C10: 56n; C_UNIV_THT2p54_SMD1206
C11, C12: 10u; C_UNIV_THT2p54_SMD1206
C13, C14: 220p; C_UNIV_THT2p54_SMD1206
C15, C16: 2n2; C_UNIV_THT2p54_SMD1206
JP1, JP2: Jumper_2_Small_Bridged; Jumper_P2.54mm_D0.7mm; not fitted
R5, R6: 10k; R_UNIV_AXIAL10p16_SMD1206
R7: 1k; R_UNIV_AXIAL10p16_SMD1206
R8, R9, R10, R11: 82; R_UNIV_AXIAL10p16_SMD1206
R12, R13: 56k; R_UNIV_AXIAL10p16_SMD1206
R14, R15: 5k6; R_UNIV_AXIAL10p16_SMD1206
U3: SN74CBT3253; SOIC-16_3.9x9.9mm_P1.27mm
U4: MCP6022; DIP-8_W7.62mm_LongPads
e1: Conn_Coaxial; SMA_Amphenol_901-144_Vertical

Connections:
+5V: C3.1, C4.1, R5.2, U3.16 (VCC), U4.8 (V+); also elsewhere on the board
GND: C3.2, C4.2, C6.2, C7.1, C8.1, C9.1, C10.1, C15.1, C16.1, R6.1, U3.1 (1~OE), U3.8 (GND), U3.15 (2~OE), U4.4 (V-), e1.2 (Ext); also elsewhere on the board
LO_I: U3.14 (S0); also elsewhere on the board
LO_Q: U3.2 (S1); also elsewhere on the board
unnamed: C6.1, R5.1, R6.2, R7.2
unnamed: C11.1, R8.1
unnamed: C12.1, R10.1
unnamed: C13.2, JP1.1 (A), R12.2, R14.1, U4.7
unnamed: C14.2, JP2.1 (A), R13.2, R15.1, U4.1
unnamed: C5.1, R7.1, U3.7 (1A), U3.9 (2A)
unnamed: C8.2, C12.2, U3.6 (1B1), U3.10 (2B1)
unnamed: C7.2, C11.2, U3.5 (1B2), U3.11 (2B2)
unnamed: C9.2, R9.1, U3.4 (1B3), U3.12 (2B3)
unnamed: C10.2, R11.1, U3.3 (1B4), U3.13 (2B4)
unnamed: R11.2, U4.3 (+)
unnamed: C14.1, R10.2, R13.1, U4.2 (-)
unnamed: R9.2, U4.5 (+)
unnamed: C13.1, R8.2, R12.1, U4.6 (-)
unnamed: C5.2, e1.1 (In)
RX_I: C15.2, JP1.2 (B), R14.2; also elsewhere on the board
RX_Q: C16.2, JP2.2 (B), R15.2; also elsewhere on the board

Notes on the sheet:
R, values determine gain 100k/100 = 1000x 20*log10(100k/100) = 60dB
R, C values determine LPF cutoff 1/(2 * pi * 27e-9 * 100) ~= 59kHz

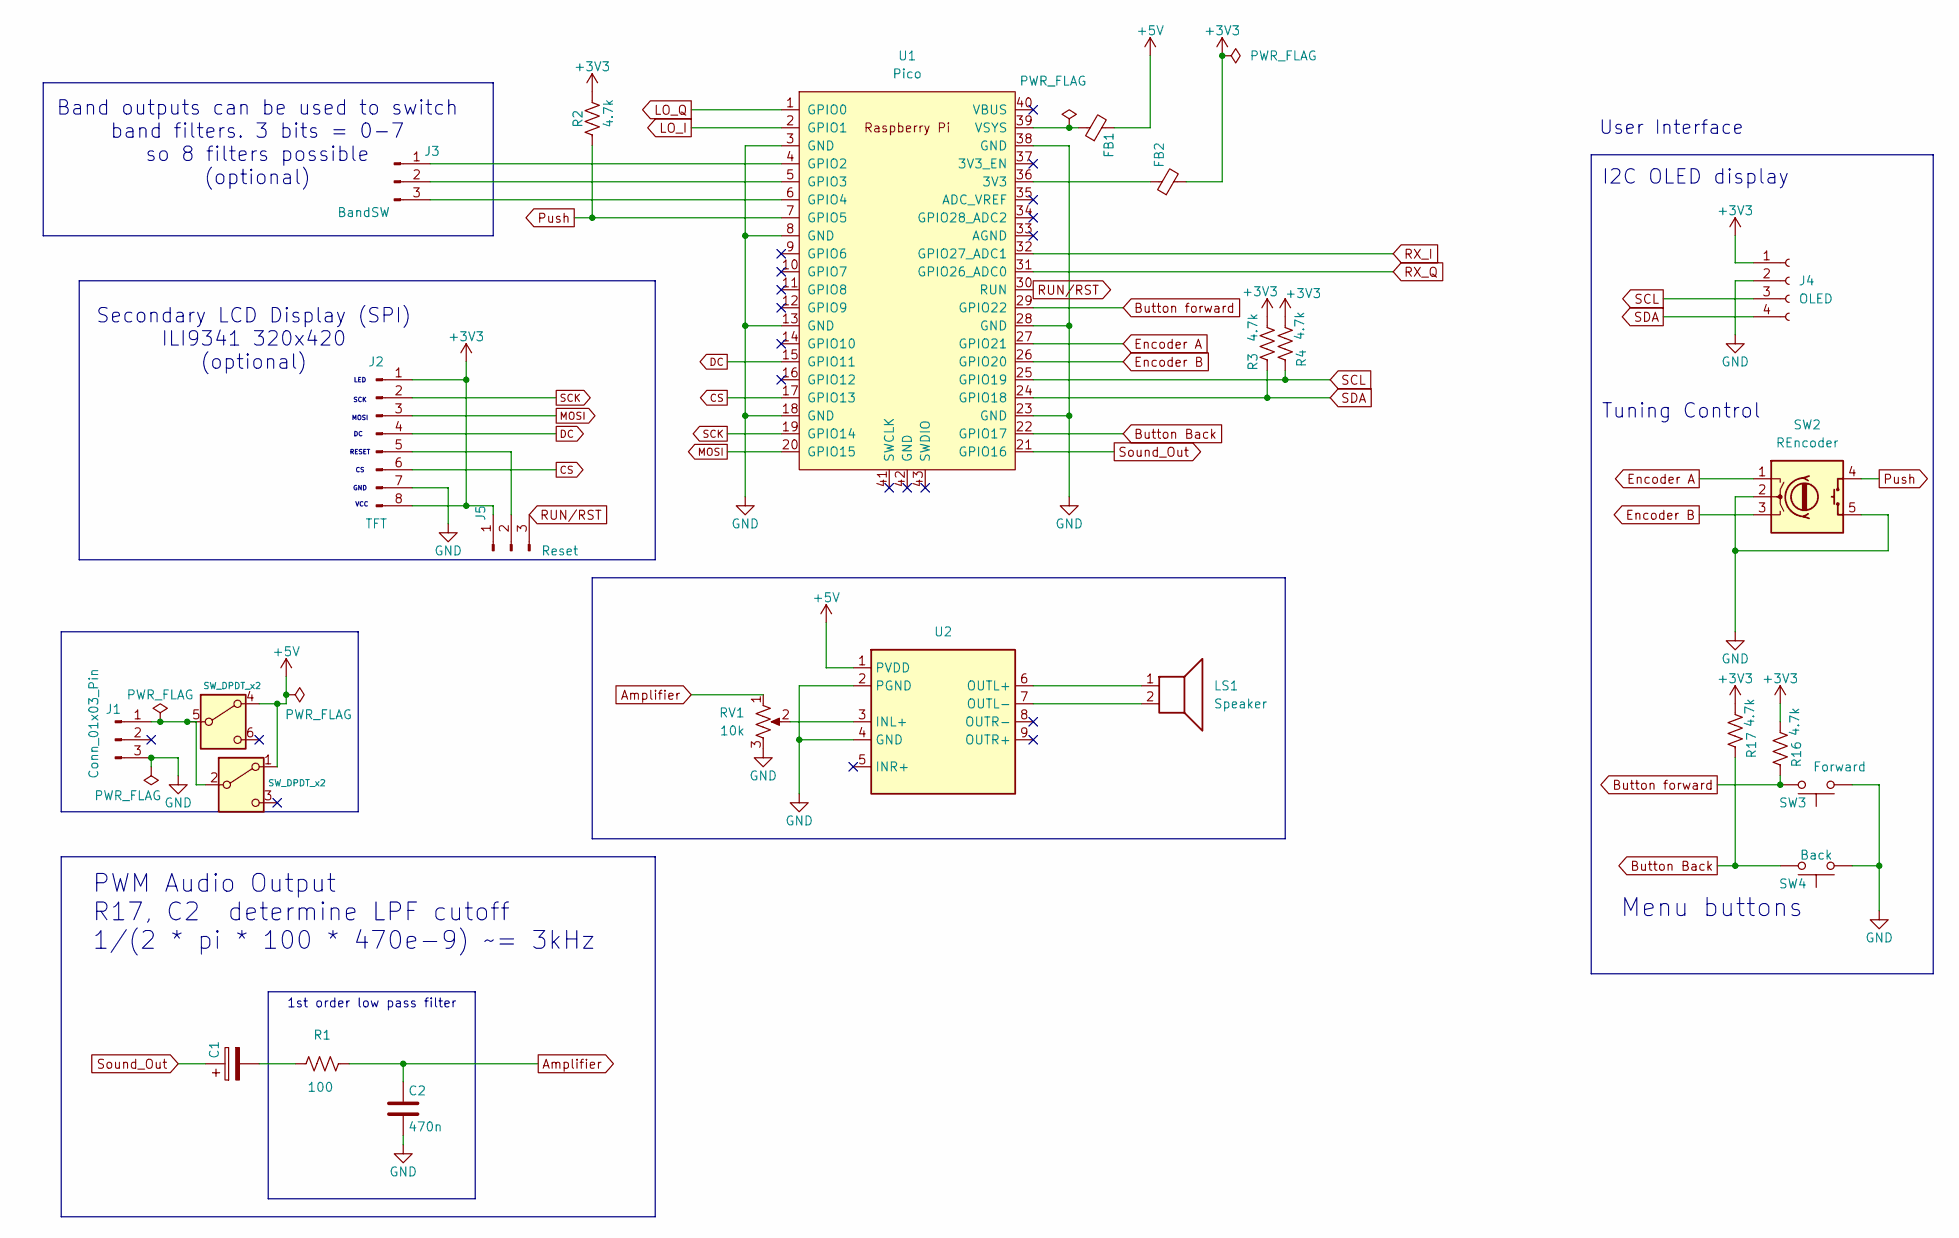
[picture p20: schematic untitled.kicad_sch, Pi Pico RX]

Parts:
C1: 100u; CP_Radial_D8.0mm_P2.50mm
C2: 470n; C_UNIV_THT2p54_SMD1206
FB1, FB2: FerriteBead_Small; R_Axial_DIN0207_L6.3mm_D2.5mm_P10.16mm_Horizontal
J1: Conn_01x03_Pin; PinHeader_1x03_P2.54mm_Vertical
J2: TFT; PinHeader_1x08_P2.54mm_Vertical
J3: BandSW; PinHeader_1x03_P2.54mm_Vertical
J4: OLED; PinHeader_1x04_P2.54mm_Vertical
J5: Reset; PinHeader_1x03_P2.54mm_Vertical
LS1: Speaker; PinHeader_1x02_P2.54mm_Vertical
R1: 100; R_UNIV_AXIAL10p16_SMD1206
R2, R3, R4, R16, R17: 4.7k; R_UNIV_AXIAL10p16_SMD1206
RV1: 10k; PinHeader_1x03_P2.54mm_Vertical
SW1: SW_DPDT_x2; SW_CK_JS202011CQN_DPDT_Straight
SW2: REncoder; PinHeader_1x05_P2.54mm_Vertical
SW3: Forward; PinHeader_1x02_P2.54mm_Vertical
SW4: Back; PinHeader_1x02_P2.54mm_Vertical
U1: Pico; RPi_Pico_SMD_TH
U2: Amplifier; rrAmpModule_32.3x26.5_photo_style

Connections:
+3V3: FB2.2, J2.1, J2.8, J4.1, J5.1, R2.1, R3.1, R4.1, R16.1, R17.1
+5V: FB1.2, SW1.1 (A), SW1.4 (A), U2.1 (PVDD); also elsewhere on the board
Amplifier: C2.1, R1.2, RV1.1
Button Back: R17.2, SW4.2, U1.22 (GPIO17)
Button forward: R16.2, SW3.2, U1.29 (GPIO22)
CS: J2.6, U1.17 (GPIO13)
DC: J2.4, U1.15 (GPIO11)
Encoder A: SW2.1 (A), U1.27 (GPIO21)
Encoder B: SW2.3 (B), U1.26 (GPIO20)
GND: C2.2, J1.3, J2.7, J4.2, RV1.3, SW2.2 (C), SW2.5 (S2), SW3.1, SW4.1, U1.3 (GND), U1.8 (GND), U1.13 (GND), U1.18 (GND), U1.23 (GND), U1.28 (GND), U1.38 (GND), U2.2 (PGND), U2.4 (GND); also elsewhere on the board
LO_I: U1.2 (GPIO1); also elsewhere on the board
LO_Q: U1.1 (GPIO0); also elsewhere on the board
MOSI: J2.3, U1.20 (GPIO15)
unnamed: C1.2, R1.1
unnamed: J1.1, SW1.2 (B), SW1.5 (B)
unnamed: J2.5, J5.2
unnamed: J3.1, U1.4 (GPIO2)
unnamed: J3.2, U1.5 (GPIO3)
unnamed: J3.3, U1.6 (GPIO4)
unnamed: FB2.1, U1.36 (3V3)
unnamed: FB1.1, U1.39 (VSYS)
unnamed: RV1.2, U2.3 (INL+)
unnamed: LS1.1, U2.6 (OUTL+)
unnamed: LS1.2, U2.7 (OUTL-)
Push: R2.2, SW2.4 (S1), U1.7 (GPIO5)
RUN/RST: J5.3, U1.30 (RUN)
RX_I: U1.32 (GPIO27_ADC1); also elsewhere on the board
RX_Q: U1.31 (GPIO26_ADC0); also elsewhere on the board
SCK: J2.2, U1.19 (GPIO14)
SCL: J4.3, R4.2, U1.25 (GPIO19)
SDA: J4.4, R3.2, U1.24 (GPIO18)
Sound_Out: C1.1, U1.21 (GPIO16)

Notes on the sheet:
1st order low pass filter
MOSI
Band outputs can be used to switch band filters. 3 bits = 0-7 so 8 filters possible (optional)
VCC
PWM Audio Output R17, C2 determine LPF cutoff 1/(2 * pi * 100 * 470e-9) ~= 3kHz
Tuning Control
GND
Menu buttons
LED
User Interface
RESET
SCK
Secondary LCD Display (SPI) ILI9341 320x420 (optional)
I2C OLED display

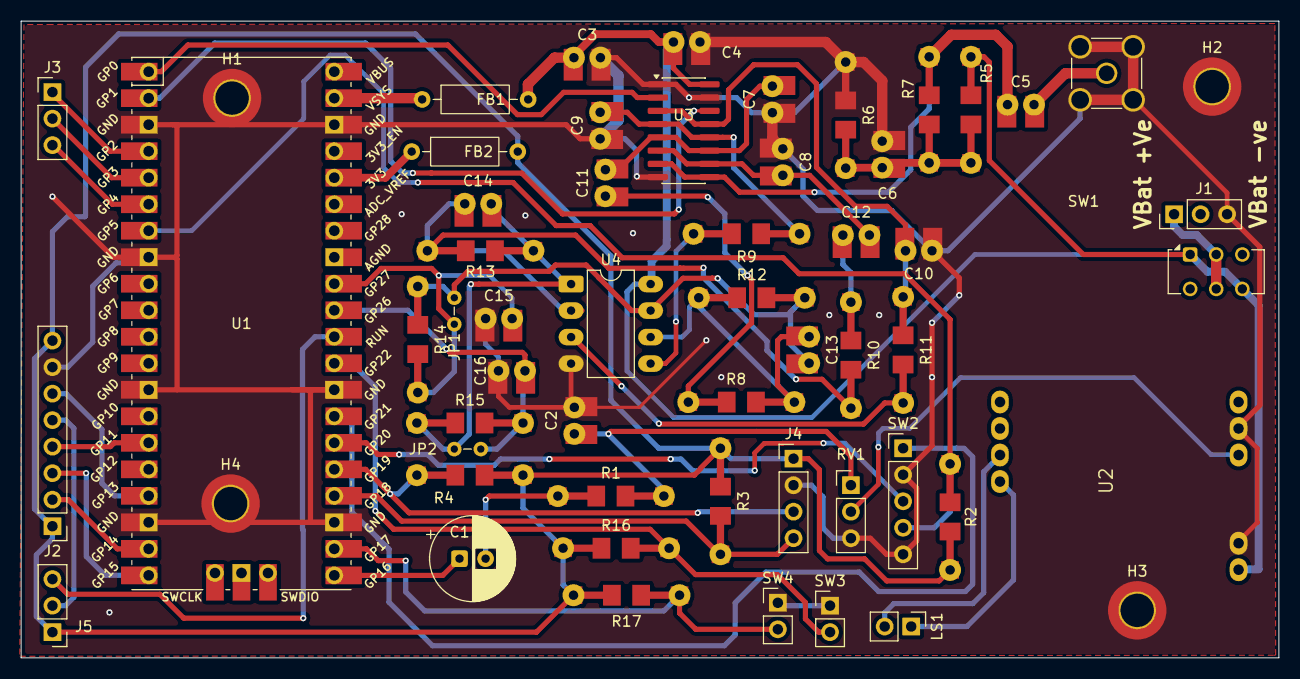
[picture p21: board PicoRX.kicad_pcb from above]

Board: 2 copper layers, 120.5 x 61.0 mm, 57 parts (0 on the bottom side), 47 nets.

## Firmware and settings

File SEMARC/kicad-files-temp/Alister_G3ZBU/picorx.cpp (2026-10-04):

#include "pico/stdlib.h"
#include <stdio.h>

#include "pico/multicore.h"
#include "pico/time.h"
#include "hardware/watchdog.h"

#include "rx.h"
#include "ui.h"
#include "waterfall.h"
#include "cat.h"
#include "hardware/uart.h"

#define UI_REFRESH_HZ (10UL)
#define UI_REFRESH_US (1000000UL / UI_REFRESH_HZ)
#define CAT_REFRESH_US (1000UL) //10ms
#define SERCAT_REFRESH_US (10000UL) //100ms
#define BUTTONS_REFRESH_US (50000UL) // 50ms <=> 20Hz
#define WATERFALL_REFRESH_US (50000UL) // 50ms <=> 20Hz

// ZBU
#define UART_ID1 uart1
#define BAUD_RATE1 19200
#define UART_TX_PIN 8
#define UART_RX_PIN 9
#define TESTPIN 7


uint8_t spectrum[256];
uint8_t audio[128];
uint8_t dB10=10;
uint8_t zoom=1;
static rx_settings settings_to_apply;
static rx_status status;
static rx receiver(settings_to_apply, status);
waterfall waterfall_inst;
static ui user_interface(settings_to_apply, status, receiver, spectrum, audio, dB10, zoom, waterfall_inst);

void core1_main()
{
    multicore_lockout_victim_init();
    receiver.run();
}

void process_sercat_control(rx_settings & settings_to_apply, rx_status & status, rx &receiver, s_settings &settings)
{
  static char cmd_buffer[64];
  static uint8_t cmd_idx = 0;

  // ZBU - this is a placeholder for processing serial CAT control commands received over UART
  // In a real implementation, this would read from the UART buffer, parse commands, and update settings accordingly
  while (uart_is_readable(UART_ID1)) {
    char c = uart_getc(UART_ID1);
    cmd_buffer[cmd_idx++] = c;
    if (c==';' ) // assuming commands are terminated with a semicolon
    {
      cmd_buffer[cmd_idx] = '\0'; // null-terminate the command string
      cmd_idx = 0; // reset index for next command
      // printf("Received CAT command: %s\n", cmd_buffer); // For testing, we can just print the received command
      
      // Here you would add code to parse the command and update settings_to_apply as needed
      if (strstr(cmd_buffer, "MD;") == cmd_buffer) // example: Poll cmd MD;;
      {
        // This is just an example of how you might parse a command. 
        uart_putc_raw(UART_ID1, 'M'); // Respond with 'M' for MD command
        uart_putc_raw(UART_ID1, 'D');
        c='0'+settings_to_apply.mode; // Convert mode to character
        uart_putc_raw(UART_ID1, c); // example mode value
        uart_putc_raw(UART_ID1, ';'); // End the response with a semicolon
      }
      else if (strstr(cmd_buffer, "MD") == cmd_buffer) // example: Set cmd MD1; (set mode to 1)
      {
        // This is just an example of how you might parse a command. 
        settings.channel.mode = cmd_buffer[2] - '0'; // Set mode to 1 based on command
      //  printf("Mode=%x\n", settings_to_apply.mode); // For testing, print the current mode
        apply_settings_to_rx(receiver, settings_to_apply, settings, false, true); // Indicate that settings have changed and need to be applied
      } 
      // clear the string buffer after processing the command
      memset(cmd_buffer, 0, sizeof(cmd_buffer));
    }
    // For testing, we can just print the received character
   
    // Here you would add code to parse the command and update settings_to_apply as needed
  }
}

void test_uart_cat()
{
  static uint32_t i;

  if (i++>1000000)
  { 
       gpio_put(TESTPIN,1);  // ZBU just to time this.
          i=0;  // this is best down when CPU clock is changed.
    uart_init(UART_ID1, BAUD_RATE1); // ZBU mods for serial CAT control
        gpio_put(TESTPIN,0);
  }
}

int main() 
{
  gpio_set_function(LED, GPIO_FUNC_SIO);
  gpio_set_dir(LED, GPIO_OUT);
  gpio_put(LED, 1);

  uart_set_format(UART_ID1, 8, 1, UART_PARITY_NONE); 
  gpio_set_function(UART_TX_PIN, GPIO_FUNC_UART);
  gpio_set_function(UART_RX_PIN, GPIO_FUNC_UART); 
  gpio_set_function(TESTPIN, GPIO_FUNC_SIO);
  gpio_set_dir(TESTPIN, GPIO_OUT);
  gpio_put(TESTPIN, 0);
  uart_set_fifo_enabled(UART_ID1, true); // Enable FIFO for less immediate response
  uart_init(UART_ID1, BAUD_RATE1); // ZBU mods for serial CAT control

  stdio_init_all();
  watchdog_enable(2000, true);
  multicore_launch_core1(core1_main);

  // create an alarm pool for USB streaming with highest priority (0), so
  // that it can pre-empt the default pool
  receiver.set_alarm_pool(alarm_pool_create(0, 16));
  user_interface.autorestore();


  uint32_t last_ui_update = 0;
  uint32_t last_cat_update = 0;
  uint32_t last_sercat_update = 0;
  uint32_t last_buttons_update = 0;
  uint32_t last_waterfall_update = 0;

  while(1)
  {

    watchdog_update();

    //schedule tasks
    if (time_us_32() - last_buttons_update > BUTTONS_REFRESH_US) 
    {
      last_buttons_update = time_us_32();
      user_interface.update_buttons();
    }
    receiver.tune();

    if(time_us_32() - last_ui_update > UI_REFRESH_US)
    {
      last_ui_update = time_us_32();
      user_interface.do_ui();
      receiver.get_spectrum(spectrum, dB10, zoom);
      receiver.get_audio(audio);
    }

    if(time_us_32() - last_cat_update > CAT_REFRESH_US)
    {
      last_cat_update = time_us_32();
      process_cat_control(settings_to_apply, status, receiver, user_interface.get_settings());
      
    }

    if(time_us_32() - last_waterfall_update > WATERFALL_REFRESH_US)
    {
      last_waterfall_update = time_us_32();
      waterfall_inst.update_spectrum(receiver, user_interface.get_settings(), settings_to_apply, status, spectrum, dB10, zoom);
    }
    
    if(time_us_32() - last_sercat_update > SERCAT_REFRESH_US)
    {
      last_sercat_update = time_us_32();
      process_sercat_control(settings_to_apply, status, receiver, user_interface.get_settings());
      
    }
    test_uart_cat(); // ZBU test code for timing serial CAT control

  }
}

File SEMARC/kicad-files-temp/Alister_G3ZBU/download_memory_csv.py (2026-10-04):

import sys
import serial
import serial.tools.list_ports
import struct
import os
import time
from channel_to_words import words_to_channel

# modified 28th Feb 2026 to detect filename's extension and
# store in CSV if the extension is .csv. G3ZBU.

if len(sys.argv) < 2 or "-h" in sys.argv or "--help" in sys.argv:
  print("Download Memory Contents from Pi Pico Rx")
  print("")
  print("Usage: python dowload_memory.py [filename]")
  print("")
  print("'filename'.csv outputs in csv format.")
  sys.exit(-1)
filename = sys.argv[1]


#prompt user for port to connect to
if os.path.exists(filename):
  print("%s exists. Replace? Y/N"%filename)
  idx = input()
  if idx.strip().upper() != "Y":
    sys.exit(-1)

print("1. Connect USB cable to Pico Rx")
print("2. When ready press any key")
idx = input()

#get a list of available serial ports
print("Available Ports")
portinfo = dict(enumerate(serial.tools.list_ports.comports()))
for idx, info in portinfo.items():
    port, desc, hwid = info
    print(idx, "{}: {} [{}]".format(port, desc, hwid))

#prompt user for port to connect to
while 1:
    print("Select COM port >")
    idx = input()
    port = portinfo.get(int(idx), None)
    if port is not None:
        port = port[0]
        break

#send csv file to pico via USB
with serial.Serial(port, 12000000, rtscts=1, timeout=1) as ser:

    #clear any data in buffer
    while ser.in_waiting:
      ser.read(ser.in_waiting)
    time.sleep(1)
    while ser.in_waiting:
      ser.read(ser.in_waiting)
# check extension...G3ZBU
    fname, fext = os.path.splitext(filename)
    
    with open(filename, 'w') as output_file:
      output_file.write("Title           , Frequency, Band Start, Band End, Mode, AGC Speed, Frequency Step, bandwdth\n")
      for channel_number in range(512):
        print("Fetching Channel:", channel_number)
        cmd = "ZDN%03x;"%(channel_number)
        ser.write(bytes(cmd, "utf8"))
        data = ser.read(135)
        data = data[6:].decode("utf8")
        data = [int(data[i*8:i*8+8], 16) for i in range(16)]
        name, frequency, min_frequency, max_frequency, mode, agc_speed, step, bandwidth = words_to_channel(data)
        if fext == ".csv":
            csvline = "%s, %u, %u, %u, %s, %s, %s, %s\n"%(name, frequency, min_frequency, max_frequency, mode, agc_speed, step, bandwidth)
        else:
            csvline = "%s %u %u %u %s %s %s %s\n"%(name, frequency, min_frequency, max_frequency, mode, agc_speed, step, bandwidth)

        output_file.write(csvline)

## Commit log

2026-09-17 Update README with SEMARC version details
    Added information about the SEMARC version of PicoRX, including PCB and Box designs, and guidelines for code modifications.
2026-10-04 Add schematics and pcb layouts
    [Bandpass.kicad_sch, Display_OLED_0.96_128x64.step, Lowpass.kicad_sch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]
